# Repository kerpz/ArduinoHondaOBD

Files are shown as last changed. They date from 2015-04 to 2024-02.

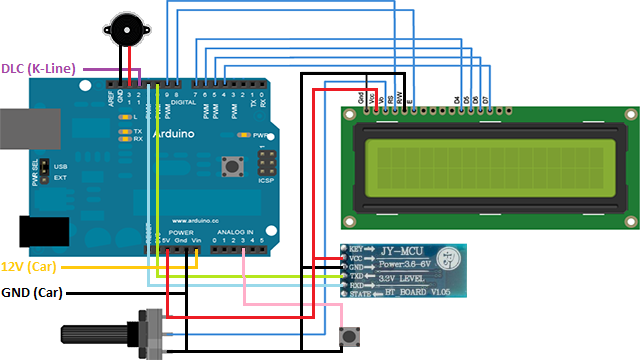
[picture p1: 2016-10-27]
images/UNI_wiring.png

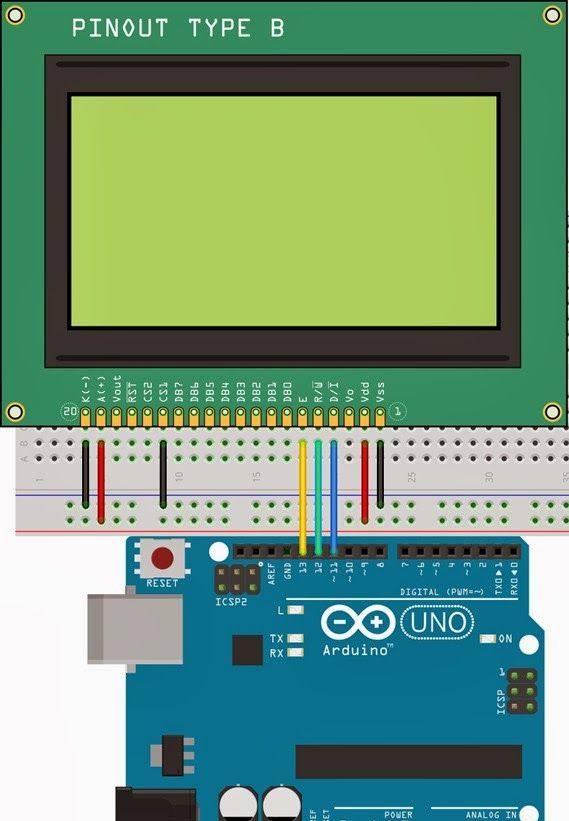
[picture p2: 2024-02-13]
hobd_u8g/wiring.jpg

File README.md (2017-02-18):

ArduinoHondaOBD
===========

An arduino code that reads Honda OBD Protocol and translates it to ELM327 protocol.
I use Torque app to read and display the data on my android phone (via bluetooth),
and a LCD (2x6) to display it on my car's dashboard.

Please refer to the screenshots below.

Applications
--------
* Datalogging
* Diagnostics
* Trip Computer
* Etc

Supports
--------
* Honda ECU's before 2002

Files
-----
* hobd_uni - unified code for ELM bluetooth and LCD display with other improvements.
* hobd_elm - implements Honda OBD to ELM OBD2 protocol (bluetooth) - not updated
* hobd_lcd - implements Honda OBD to LCD display - not updated
* UNI_wiring.png - Unified wiring diagram for arduino UNO (compatible)

Wiring for hobd_uni (Joined ELM and LCD codes)
--------------------
    Honda 3 Pin DLC           Arduino Uno
    Gnd --------------------- Gnd
    +12 --------------------- Vin
    K-line ------------------ Pin12

    HC-05 Bluetooth           Arduino Uno               
    Rx ---------------------- Pin11
    Tx ---------------------- Pin10

    LCD 16x2                  Arduino Uno               
    RS ---------------------- Pin9
    Enable ------------------ Pin8
    D4 ---------------------- Pin7
    D5 ---------------------- Pin6
    D6 ---------------------- Pin5
    D7 ---------------------- Pin4
    VO ---------------------- 10k Potentiometer (+5V to Gnd)

    Piezo Buzzer              Arduino Uno               
    (+) --------------------- Pin13
    (-) --------------------- Gnd

    Tact Switch               Arduino Uno               
    (+) --------------------- Pin17 (A3)
    (-) --------------------- Gnd

    Voltage Divider           Arduino Uno               
    +12V divider circuit ---- Pin14 (A0)
    (680k ohms and 220k ohms)

UNI Wiring Image

Wiring for hobd_elm (Deprecated use hobd_uni)
--------------------
    Honda 3 Pin DLC           Arduino Uno
    Gnd --------------------- Gnd
    +12 --------------------- Vin
    K-line ------------------ Pin12

    HC-05 Bluetooth           Arduino Uno               
    Rx ---------------------- Pin11
    Tx ---------------------- Pin10

Wiring for hobd_lcd (Deprecated use hobd_uni)
---------------
    Honda 3 Pin DLC           Arduino Uno
    Gnd --------------------- Gnd
    +12 --------------------- Vin
    K-line ------------------ Pin12

    LCD 16x2                  Arduino Uno               
    RS ---------------------- Pin9
    Enable ------------------ Pin8
    D4 ---------------------- Pin7
    D5 ---------------------- Pin6
    D6 ---------------------- Pin5
    D7 ---------------------- Pin4
    VO ---------------------- 10k Potentiometer (+5V to Gnd)

Screenshots (LCD 16x2)
---------------

LCD Screenshot 01
LCD Screenshot 02
LCD Screenshot 03

Screenshots (Andorid App TORQUE)
---------------

TORQUE Screenshot 01
TORQUE Screenshot 02
TORQUE Screenshot 04
TORQUE Screenshot 03

NOTES
-----
* Added button for changing page (5ms) and changing ecu mode (3s).
* Added Fault codes reader @ lcd page 3
* Added LCD @ I2C support
  - #define LCD_i2c TRUE // Using LCD 16x2 I2C mode
* Added direct HOBD access API (ELM mode) used for undefined PIDs on OBD2
  - // direct honda PID access
  - // 1 byte access (21AA) // 21 = 1 byte, AA = address
  - // 2 bytes access (22AA) // 22 = 2 bytes, AA = address
  - // 4 byte access (24AA) // 24 = 4 bytes, AA = address
* Added direct Arduino Pin access API (ELM mode) used for keyless entry and other stuff
  - // set arduino pin (ATSAPNNX) // NN = pin, X = value (value is 1 or 0)
  - // get arduino pin (ATDAPNN) // NN = pin
* Tested on P2T ODB2 stock and P30 ODB1 chipped

TODO
-----
* Add 128x64 LCD @ SPI support
* Add 20x4 LCD @ I2C support

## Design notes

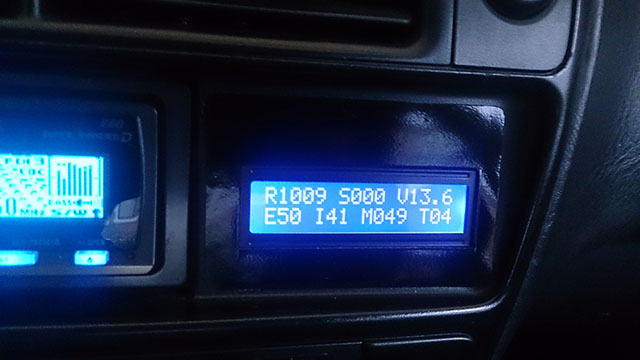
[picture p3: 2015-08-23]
images/LCD_02.png

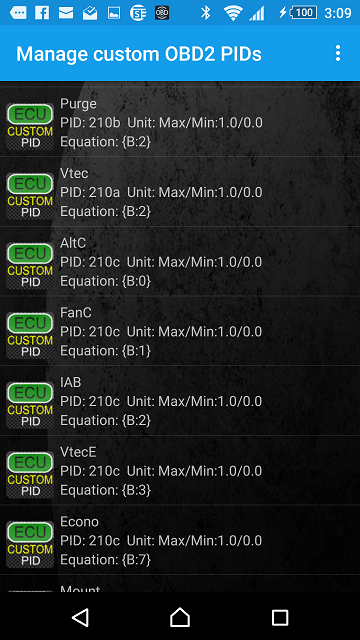
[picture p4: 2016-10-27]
images/TORQUE_05.png

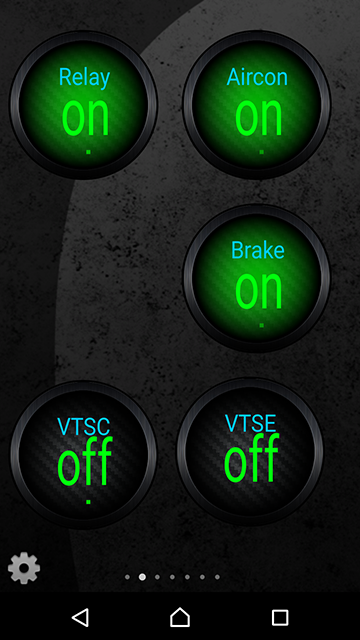
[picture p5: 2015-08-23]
images/TORQUE_03.png

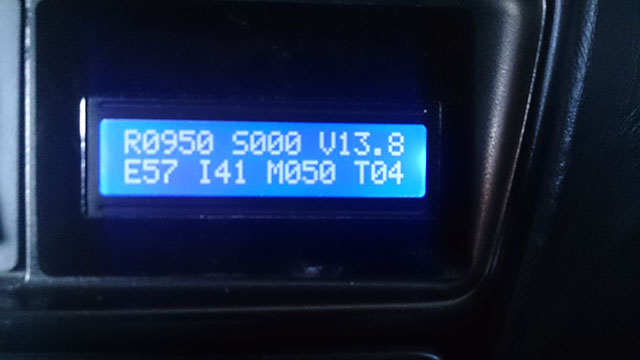
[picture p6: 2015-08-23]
images/LCD_03.png

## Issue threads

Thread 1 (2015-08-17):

Run on Nano with 328P ?

mr-sneezy, 2015-08-17:
I'm keen to try this code out on my Honda from 1999.
It looks like the code would run on Arduino Nano with 328P which I already have on hand.
Would there be some reason that it would not be suitable ?
Regards,
Martin

kerpz, 2015-08-17:
Hi martin,

It should run fine on a 328p chip, in fact Im running on a DIY board with 328 chip and UNO bootloader.

Regards, 

Philip B.

Sent from Yahoo Mail on Android

From:"Martin" <notifications@github.com>
Date:Mon, Aug 17, 2015 at 5:19 PM
Subject:[ArduinoHondaOBD] Run on Nano with 328P ? (#1)

I'm keen to try this code out on my Honda from 1999.
It looks like the code would run on Arduino Nano with 328P which I already have on hand.
Would there be some reason that it would not be suitable ?
Regards,
Martin

—
Reply to this email directly or view it on GitHub.￼

mr-sneezy, 2015-08-18:
Great, I did think there would be no problem, but it's good to get
confirmation.

I'll put this all together later this week and see how it goes on the
weekend hopefully.
If you want I'll take some photos and make an Eagle schematic for your
documentation on Github.

I'd like to add some code for checking error codes, and I'm wondering if
there is enough CPU time available to run a OLED display in lieu of the
16x2 Hitachi.

Regards,
Martin

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

---
This email has been checked for viruses by Avast antivirus software.
https://www.avast.com/antivirus

kerpz, 2015-08-19:
Hi martin,

That would be a great contribution.

Thanks and more power :)

Sent from Yahoo Mail on Android

From:"Martin" <notifications@github.com>
Date:Tue, Aug 18, 2015 at 7:35 PM
Subject:Re: [ArduinoHondaOBD] Run on Nano with 328P ? (#1)

Great, I did think there would be no problem, but it's good to get
confirmation.

I'll put this all together later this week and see how it goes on the
weekend hopefully.
If you want I'll take some photos and make an Eagle schematic for your
documentation on Github.

I'd like to add some code for checking error codes, and I'm wondering if
there is enough CPU time available to run a OLED display in lieu of the
16x2 Hitachi.

Regards,
Martin

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

---
This email has been checked for viruses by Avast antivirus software.
https://www.avast.com/antivirus

—
Reply to this email directly or view it on GitHub.￼

mr-sneezy, 2015-08-22:
Update:
The sketch is running on the Nano fine, 16x2 LCD is working fine.
Added HC-05 module and set to 9600baud.
I now have the HC-05 bluetooth talking to Torque app.
I have 'Bluetooth Mode' indication on the LCD.
I see data on the K line pin on the breadboard.
I am yet to connect to the car because my Ebay cable has not arrived, I'll need to make something temporary to do it.

Philip, do you have a blog or other site where a discussion can be done  ?

kerpz, 2015-08-22:
Hi Martin,
The discussion was done at pgmfi.org before, but I think the site is down.BTW, I'll post some pictures I grabbed from my phone and my car.
Regards,Philip

     On Saturday, August 22, 2015 4:20 PM, Martin <notifications@github.com> wrote:

 Update:
The sketch is running on the Nano fine, 16x2 LCD is working fine.
Added HC-05 module and set to 9600baud.
I now have the HC-05 bluetooth talking to Torque app.
I have 'Bluetooth Mode' indication on the LCD.
I see data on the K line pin on the breadboard.
I am yet to connect to the car because my Ebay cable has not arrived, I'll need to make something temporary to do it. Philip, do you have a blog or other site where a discussion can be done ?—
Reply to this email directly or view it on GitHub.

mr-sneezy, 2015-08-26:
I see the photos Philip, looks great. Looking forward to getting mine finished soon too.
BTW in researching the Honda OBD protocol I found a list of dlc command requests somebody has compiled, around 200 of them. Do you have something like that already to work from already ?
I could post it here.

kerpz, 2015-08-26:
Yes, anything that could improve this project would be a great help. I think there's a lot to be done in here. code faults scanning is not yet implemented.

mr-sneezy, 2015-08-27:
I hope this is actually useful, I'm collating and cleaning it all up after a google translation (for my own use anyway). This is not the list I mentioned above, as I don't think that one is very relevant after another look at it today. Will look over it again later.

The info below is headed by a URL to the source before each section, so credit goes to the original poster for documenting the info, not me.
There is a fragmented description of 32 bytes of DTC (from 0x40h to 0x50h it says in the second section) that may help out, also mention of ECU ID on 0x76h in that second block of info.
--------------------------------------------------------------------
[about Fault Codes ?]
http://hondamotor.ru/board/index.php?showtopic=98035&st=80&p=1626275&#entry1626275

Total: in the log can fall 32 bytes to describe the error.
These 32 bytes are the description of the 64 bugs.
 such a response is as follows: 00 02 00 20 ... (Hex View)
numbering errors in Honda starts with 0 (0-error ECU, 1 - error of the first sensor O2, 2 - the second O2 sensor error ...)
 in this example
00 ------> (lower 4 bits 0, upper 4 bits 0) ---> 0 - error0 (no)  0 - error1 (no)
02 ------> (lower 4 bits 2, upper 4 bits 0) ---> 2 - error2 (yes) 0  -error3 (no)
00 ------> (lower 4 Bits 0, upper 4 bits 0) ---> 0 - error4 (no)  0 - error5 (no)
20 ------> (lower 4 bits 0, upper 4 bits 2) ---> 0 - error6 (no)  2 - error7 (yes)
...........................
So Makar parse all 32 bytes. (The error codes are the same as blink codes) checked in several logs. And local expo error falls under the reduced treatment.
 
[about Command values (including DTC?) ?]
http://hondamotor.ru/board/index.php?showtopic=98035&st=120
The amount is considered to be just 256 minus the sum of all the bytes of the request or response, if it turns out is less than 0, then add 256
Enum ValuesOffset: byte
RPM = 0x00, // Turnover (2 bytes)
VSS = 0x02, // speed
Flag1 = 0x08, // 15 0-SW Starter 1-SW AC 3-SW Brake
Flag2 = 0x09, // 16 3- SCS self-diagnosis
Flag3 = 0x0A, // 17 2-VTS Vtec Control
Flag4 = 0x0B, // 18 0-MainRelay 2-O2Heater 5 -Engine
Flag5 = 0x0C, // 19 3-VTEC E 7-Econo
Flag6 = 0x0D, // 20
Flag7 = 0x0E, // 21
Flag8 = 0x0F, // 22
ECT = 0x10, // pace antifreeze
IAT = 0x11, / / temperature
 MAP = 0x12, // the pressure in the inlet
PA = 0x13, // atmospheric pressure T
PS = 0x14, // dross valve sensor
O2 = 0x15, // lambda sensor or lean
Bat = 0x17, // voltage onboard network
ALTF = 0x18, // Alternator FR Signal (ALTF) signal control board voltage
CorrCT = 0x20, // krastkovremennaya fuels correction
CorrLT = 0x22, // fuels long-term correction
Inj = 0x24, // ignition (2 bytes)
InjAdv1 = 0x26, // something with the ignition
InjAdv2 = 0x27, // something with the ignition
IAC = 0x29, // The Idle air control valve, or IACV regulates the car's idle based on the coolant temperature.
Knock = 0x3C, // Knock Sensor

Errors1 = 0x40, // Pars half a byte, half-byte if not equal to 0, it means
Errors2 = 0x50, // there is such an error code. Error number - offset nibbles displacement starts from 0
VSS2 = 0x61, // speed
RPM2 = 0x62, // Turnover (2 bytes)
ECT2 = 0x64, // pace antifreeze
IAT2 = 0x65, // temperature
MAP2 = 0x66, // the pressure in the inlet
PA2 = 0x67 // Atmospheric pressure
TPS2 = 0x68, // dross sensor zaslonui
Bat2 = 0x69, // voltage onboard network
O22 = 0x6C, // lambda sensor or lean
CorrCT2 = 0x6D, // krastkovremennaya fuels correction
IAC2 = 0x6E, // The air control valve Idle, or IACV regulates the car's idle based on the coolant temperature.
ECUID = 0x76 // ECU ID

Flags]public enum HOBDFlags: ulong
AllOff = (ulong) 0
Starter = 1 << 0
AirCondition = 1 << 1
PASPressure = 1 << 2
VTECPressure = 1 << 7
Brake = 1 << 3
SCS = 1 << (3 + 8), self-diagnostics //
VTSControl = 1 << (+16 2)
MainRelay 1 << = (0 + 24)
O2Heater << 1 = (2 + 24)
CEL = 1 << (5 + 24)
Engine 1 << = (5 + 24)
VTEC_E = 1 << (3 + 32)
Econo = 1 << (7 + 32)
ACClutch = 1 << (1 + 24)
O2Heater2 << 1 = (6 + 24)
FAN = 1 << (1 + 32)
------------------------------------------------------------------------
If it's all useless rubbish then I apologize in advance :)

mr-sneezy, 2015-08-27:
I have no idea why I have bold text in the last line, it's not shown while editing....

kerpz, 2015-08-28:
Yup found that already, but will double check maybe i missed something.  ￼ 

Sent from Yahoo Mail on Android

From:"Martin" <notifications@github.com>
Date:Thu, Aug 27, 2015 at 5:20 PM
Subject:Re: [ArduinoHondaOBD] Run on Nano with 328P ? (#1)

I have no idea why I have bold text in the last line, it's not shown while editing....

—
Reply to this email directly or view it on GitHub.￼

mr-sneezy, 2015-08-28:
These bits were of most interest perhaps.

Errors1 = 0x40, // Pars half a byte, half-byte if not equal to 0, it means
Errors2 = 0x50, // there is such an error code. Error number - offset nibbles displacement starts from 0

Total: in the log can fall 32 bytes to describe the error.
These 32 bytes are the description of the 64 bugs.
such a response is as follows: 00 02 00 20 ... (Hex View)
numbering errors in Honda starts with 0 (0-error ECU, 1 - error of the first sensor O2, 2 - the second O2 sensor error ...)
in this example
00 ------> (lower 4 bits 0, upper 4 bits 0) ---> 0 - error0 (no) 0 - error1 (no)
02 ------> (lower 4 bits 2, upper 4 bits 0) ---> 2 - error2 (yes) 0 -error3 (no)
00 ------> (lower 4 Bits 0, upper 4 bits 0) ---> 0 - error4 (no) 0 - error5 (no)
20 ------> (lower 4 bits 0, upper 4 bits 2) ---> 0 - error6 (no) 2 - error7 (yes)
...........................
So Makar parse all 32 bytes. (The error codes are the same as blink codes) checked in several logs. And local expo error falls under the reduced treatment.

mr-sneezy, 2015-08-28:
I note that the author suggests that the error code match the blink code numbering. Would seem logical.

kerpz, 2016-06-24:
Working, on adding this stuff

mr-sneezy, 2016-06-24:
Cool.
As it happens I've restarted the customisation of your code to add some external sensors (3x DS18B20's), to report through to the Torque app. I've dropped the LCD code as it's going to be hard to get enough data on it for my liking and I don't really want to mount a permanent LCD in a classic car like the S2000.
What may help us both is that I have a bench test ECU running now, with original MAP and ECT plus pots for TPS, IAT, O2. With this I could force on fault codes to test with you.
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

kerpz, 2016-06-25:
Wow, that's great :)

Closed 2021-05-30.

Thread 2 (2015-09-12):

Success and feedback.

mr-sneezy, 2015-09-12:
Hi Philip.
I took the Ebay Honda OBDII cable and cut off the 16-pin plug end (mine came wired for CAN on pin-14 not K-line on pin-7 anyway). I connected up the ArduinoNano/LCD/Bluetooth on the protoboard to it, and we had nearly instant success on my 1999 Honda S2000 (Australian delivered version). I get data from the HondaOBD converter on my Android phone through the Torque app, I just had to set the adapter speed to slow in the Torque settings first.

Feedback.
I have not yet fully setup Torque with the relay indications like you have, but the basics were working with the default gauge set.
The data mostly looks right, but coolant temp indicates around 100C at a real measured 80C (I used a thermocouple gauge on the radiator hose near the engine and then confirmed again with an IR thermo gun).
Also the coolant temp reads 155C on Torque when the car is off but the Arduino and BT are on. Would be better perhaps to read 0C when there is no valid ECU data perhaps, if this can be done.
The data refresh rate is quite slow on torque, I have not looked at how you set the request timing but it would be nice to update data faster if it's at all possible.
Would you know what the theoretical max baud or request rate of the ECU is ?

I'll have another look at your Torque screen photos and setup my Android device the same and have another look at it tomorrow.
Now that it's running on the protoboard I'm intending to create an Eagle PCB for it. I'll mount the Nano module, the Bluetooth module and regulator on it. LCD too probably but I don't like the white-on-blue one I have right now and will source another. Also going to see what I can do about some indicator leds on the K-line side as some comms feedback to the user (it's nice to know it's running on the ECU side).
Thanks,
Martin

kerpz, 2015-09-13:
Awesome

About the coolant values the readings comes from th ECT sensor, which is attached on the engine block. and when the car is off I think the reading will be the last data since it will return a NO_DATA value.

mr-sneezy, 2015-09-14:
Philip have you considered putting a warning LED driven from the Arduino, that triggers at preset ECT (say 100C) ?
I am looking for a RGB backlit 16x2 LCD as an option to change colour when values go out of normal range. Adafruit has them, and few other vendors...

kerpz, 2015-09-15:
Yes, I have them in the latest commit, I used it to avoid overheating, the current value is 98 degrees. I used a piezo buzzer at pin 13

Sent from Yahoo Mail on Android

From:"Martin" <notifications@github.com>
Date:Mon, Sep 14, 2015 at 6:07 PM
Subject:Re: [ArduinoHondaOBD] Success and feedback. (#2)

Philip have you considered putting a warning LED driven from the Arduino, that triggers at preset ECT (say 100C) ?
I am looking for a RGB backlit 16x2 LCD as an option to change colour when values go out of normal range. Adafruit has them, and few other vendors...

—
Reply to this email directly or view it on GitHub.￼

Closed 2021-05-30.

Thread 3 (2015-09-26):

Question about ECT formula ?

mr-sneezy, 2015-09-26:
Hi Philip, where did you get the formula for the ECT calculation in degrees C ?
Regards,
Martin

kerpz, 2015-10-02:
I think from the hondamotors.ru furom they have the formula

mr-sneezy, 2015-10-04:
I found a look up table apparently read from an OBD1 ECU if I understand it right. here on an old Honda forum.
http://www.getglitched.com/pgmfiwiki/www.pgmfi.org/twiki/bin/view/Library/EngineCoolantTemperature.html
If it's valid then it perhaps could be used as a table in in the HondaOBD code, or used to validate the formula currently used.

I also found this website which can derive the formula for you from points on the curve.
http://rusefi.com/articles/measuring_temperature/Steinhart-Hart.shtml

Here's the sensor curve that Honda quote for sensor testing.
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

mr-sneezy, 2015-10-04:
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

kerpz, 2015-10-14:
nice

kerpz, 2015-10-14:
why is the E16 is less than I17 intake is hotter than the engine :D

Closed 2021-05-30.

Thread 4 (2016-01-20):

connect with chrome ecu software

dibugreen, 2016-01-20:
hi ..
i'm blind about arduino :).. wuff ..  see lot of awesome project based n arduino .. including this one :)..
is possible to connect your project with  FT232RL FTDI USB to TTL ..(maybe chrome application will accept this communication..)
sorry for my english..
and thx for advance

kerpz, 2016-01-26:
Yes, you can use arduino to connect your ecu to crome application, eliminating the use of usb ftdi to ttl connector.

dibugreen, 2016-01-29:
thx  very much .. i'll try lean arduino .of course based on your project help me very much  ..thx u very much sir ..

mr-sneezy, 2016-01-30:
Crome PC app connection.
Do you both mean to a PC via the bluetooth link ?
If so what Hardware and Port setting are used in Crome to connect to a stock ECU ?
Regards,
Martin

kerpz, 2016-03-07:
yes I think its possible with bluetooth too.

Closed 2021-05-30.

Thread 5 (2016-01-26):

List of DLC values and meanings ?

mr-sneezy, 2016-01-26:
Hi Philip,
I've recently forked your Arduino code and am attempting to add some features to it like additional temperature sensors..
I've been digging for Honda DLC command and response info from all over the place, but it occurs to me that you may have collated a sanitised list or spreadsheet of known values and new ones you may have found.
Would you have a document to share ?
It will allow me to reduce the overhead of trying to filter out bad info and do more coding.

Regards,
Martin

Closed 2021-05-30.

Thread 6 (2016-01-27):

Creation of the PID's supported bytes ??

mr-sneezy, 2016-01-27:
Hi Philip,
I've been trying to reverse the OBDII PID supported bytes you send to Torque, but I'm having trouble making sense of them.
else if (!strcmp(btdata1, "0100")) {
    sprintf_P(btdata2, PSTR("41 00 BE 3E B0 11\r\n>"));

I think BE 3E B0 11 are the bytes sent indicating to Torque which of the next 20h PID numbers are used (valid). I can't make sense of the bits though when converted to 32 bits (flags) compared to what's available from the Honda OBD (converted to OBDII numbering).
Is BE the high byte and 11 the Low ?
Did you create some sort of table to describe these bytes from HOBD to OBDII ?

kerpz, 2016-01-27:
Hi Martin,

I used this as my reference https://en.wikipedia.org/wiki/OBD-II_PIDs and the 0100 is a hardcoded reply which is based from https://en.wikipedia.org/wiki/OBD-II_PIDs#Mode_1_PID_00.

mr-sneezy, 2016-01-28:
Hi Philip,  thanks I used that reference too, I converted the four Hex values to 32 bits of binary as they describe but I can't see it align with the OBDII PIDs used by the code. If you have it can you post the binary strings you used to create the Hex bytes, it will help me know what I'm doing wrong from the Wiki info  (I hope).

mr-sneezy, 2016-01-28:
Also just see that the last bit of the four bytes is a flag to validate the next sequence 32 bits....
:{

mr-sneezy, 2016-01-28:
Also, I think the code you wrote below is not needed as the next flag PID after 20h is at 40h, not 30h

else if (!strcmp(btdata1, "0130")) {
    sprintf_P(btdata2, PSTR("41 30 20 00 00 01\r\n>"));

Excuse me if wrong :)

kerpz, 2016-02-03:
Yes, its a dead code afaik :)

Closed 2021-05-30.

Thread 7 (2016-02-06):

Using bit values in Torque app, not working for me ?

mr-sneezy, 2016-02-06:
Hi Philip,
Hey you may be able to help me understand why I can get the Torque app to show active relays and switches like you do, even though the ECU and Arduino are TX'ing the byte correctly to Torque.
 In the 'Test' function of the app's Edit Custom OBD2 PID editor (same as you images but in the edit option) I can see the brake and A/C flag bit changing in the third byte of the returned string shown, but I can't see the Equation output change from 0.0 when using the bit formula you use.

In your photos you show the method to get the bits from byte B, but should that not be byte C going by what the Torque app wiki says ?

Index number of byte in response denoted by Latin alphabet:
A-1 byte, B-2 byte,.., Z-26 byte,AA-27 byte,AB-28 byte,...BA,BB,...

Torque Pro Operations (For reference only)
abs(): Absolute value.
{X:B}: Verify if the bit B is set within the X byte.
[pid]: Refers to the pid number of a sensor.
val{Long Name}: Refers to another equation using its long name.

I actually tried A, B and C bytes in turn and still get no change  in the formula output or the virtual indicators...

mr-sneezy, 2016-02-06:
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

A screen shot with A/C active in byte string  but not showing in formula..

kerpz, 2016-02-08:
i think its reverse try {B:6}

mr-sneezy, 2016-02-09:
No, it turns out that Torque Pro (current version) takes the first three bytes of the Extended PID response to be header bytes, the fourth byte is A, the fifth is B, six is C etc. This is not documented any place I could see (the three bytes bit).
So the fix was too pad your 20XX commands with an extra byte, then torque works.
The equation that works then for Brake for example is {A:3}
For one of my extra temp sensors as an Extended PID it's just A

dibugreen, 2016-02-09:
what  protocol is using when connect to torque.thx

mr-sneezy, 2016-06-18:
Seems to be changed now that I updated the Torque app to the current app version. Back to your byte/bit conversion values and it works on my test ECU (now using a 1995 Accord ECU on my bench).

kerpz, 2016-06-20:
Awesome

Closed 2021-05-30.

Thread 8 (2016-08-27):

help with obd

tycs03, 2016-08-27:
hi sir, i was wondering if this code will also work for a arduino nano clone. i tried to compile the file and upload it to the nano and wired an hc-06 bluetooth adapter. the code i used was the hobd_elm. i followed the schematic you provided and wired up the bluetooth module to the arduino nano. i wired the rx d11 and tx to d10, k line to d12. im not really sure if that is correct but it seem logical to me. i have downloaded the torque app but seemed to be a totally diffrent app(updated), based on your photo.
torque app won't connect to at all gets nothing

kerpz, 2016-08-31:
Maybe you can try the hobd_uni, and you need to pair your hc-06 to your phone. BTW, what's the error?

tycs03, 2016-08-31:
i have tried hobd_uni, also i have paired my hc06 to my phone. torque app says no data did you select the right device. seems to be like arduino is not sending anything. By the way i am using a jdm p30 ecu (obd1) i was wondering if i could just wire the arduino directly inside the ecu ? using cn2 port ? i have checked dlc pins and everyting seems to be connected properly. i am thinking maybe i compiled the sketch incorrectly ? i have not much experience with arduino i just bought one cause i saw this hub of yours.

kerpz, 2016-08-31:
I've tested on p2t odb2 and p30 obd1, try to test with elm terminal app.

mr-sneezy, 2016-08-31:
I've tested on Nano with a P0A and a PCX OBDI ECU with no issues either...
If you are building on a protoboard then add indicator LED's with 1k resistors to the TX and RX to bluetooth module, and also to the ECU DLC pin from the Nano. This will tell you what the Arduino is doing easier.
Also the HC06 module needs to be set to use 9600 baud IIRC, and the activity LED should change from fast flash to slower double flash if the Android phone is connecting.

tycs03, 2016-09-01:
i have set the baud rate for the hc06 at 38400 could this be the issue, i set it this way, because chrome rtp requires this baud rate. il try to set it at 9600 see if it works. no its not on a proboard. i just soldered the wires directly to the arduino nano points as i don't have a proto board.

tycs03, 2016-09-01:
Well its working now. Only problem now is that rpm seems to be off. When i rev the engine the meter goes down to 0rpm?

tycs03, 2016-09-01:
And also the rpm is off. Im not sure about the other sensors like ect temp. And map

kerpz, 2016-09-01:
If you are using hobd_uni, the default proto is obd2, set it to obd1 since you are using p30 ecu. Btw are you using hc06 to tune your ecu? Chrome rtp?

tycs03, 2016-09-01:
How to set it to obd1? I haven't  really started to tune my car. I haven't even had the time to install the afr wideband.

tycs03, 2016-09-01:
Also tps has no signal?  (throttle)

tycs03, 2016-09-01:
I was planning to use the hc06 to data log. Althoug seems like the data stream seems to show some lag. Maybe il just use the ttl serial cable instead

tycs03, 2016-09-01:
I forgot currently i am using a stock jdm p30.  But i also have a chipped p28 ecu that i will be using to tune the engine.

tycs03, 2016-09-01:
Ok everything is working now. I was womdering if there  was some way to get tps to work?

kerpz, 2016-09-02:
All sensors are working fine with me.

tycs03, 2016-09-02:
Im not getting anu reading on throttle? And it shows a question mark. When i try to add a display

tycs03, 2016-09-02:
My bad everything is working. Thank you

tycs03, 2016-09-03:
Sir Philip is it possible to add pid for power steering switch?  I have tried the other pid and it works.  I have been meaning to test the brake switch that goes to the ecu and with i this confirmed it to be working. :-) also i have learned the characteristics of the eld. With the ALT PID this is a very nice diagnostic tool as well. Would be really great if it can also pull trouble codes from the ecu.

kerpz, 2016-09-07:
Yes, you can add it through Manage PIDS in torque's setting

tycs03, 2016-09-07:
Sir i dont really know anything about hex.  How do you get the hex values?

kerpz, 2016-10-27:
Hi haven't decode the power steering switch :(

fifthaxe, 2018-06-08:
@tycs03 did you successfully managed to plug the arduino on the CN2 port of your ECU ? Is the CN2 port and the DLC port the same ?

tycs03, 2018-06-13:
Hi. I wasnt able to do the obd gauge. I sold my car. As dlfar as i know its
cb2 and dlc port is not the same.

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

tycs03, 2018-06-13:
I was able to make the dlc using stock ecu. I never tried to connect it to
cn2 port. My objective for this was to be able to see data from a stock
ecu. Since obd1 ecu runs modfied code you i can see data from a computer.
Uaing crome

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

tycs03, 2018-06-13:
Oh by the way i have an obd1 with crome and i used bluetooth hc06 to
connect to tuner view. So i use your code on obd2 ecus. Sorry for the
confusion. I though you were the other guy i asked helped from. I never got
to try his code.

Regards,

Tycs03

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
>>> @tycs03 <https://github.com/tycs03> did you successfully managed to
>>> plug the arduino on the CN2 port of your ECU ? Is the CN2 port and the DLC
>>> port the same ?
>>>
>>> —
>>> You are receiving this because you were mentioned.
>>> Reply to this email directly, view it on GitHub
>>> <https://github.com/kerpz/ArduinoHondaOBD/issues/8#issuecomment-395807199>,
>>> or mute the thread
>>> <https://github.com/notifications/unsubscribe-auth/AUSqfL3mHlQfAxwtaecLKsoEHN7KVyQkks5t6p-ngaJpZM4JureS>
>>> .
>>>
>>

akilamarquiel, 2018-06-13:
hi guys. ever wonder of using wifi instead of a bluetooth?

Closed 2021-05-30.

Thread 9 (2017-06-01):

torque app not working on hobd_uni

abdullah381, 2017-06-01:
hello
you did very nice job btw. i appreciate your efforts. i used your sketch for my obd1 honda hobd_elm connects to torque app i need to know that can i get the fuel injection rate in miliseconds?

2nd question is the main question. i used hobd_uni . device display everything on lcd but torque app is nt connecting can you please explain the issue however torque is working fine on hobd_elm.
also i am getting rpm in wrong format for example if rpm is 1300 lcd showing 300 in hobd_uni. very most digit is not working ..

Waiting for your Replay
Thanks for wonderful inovation

kerpz, 2017-06-03:
Hi,
For Question #1 injector duration in ms is given and displayed on LCD page 2
For Question #2 (what ecu are you using? obd1 or obd2) the dafault mode is obd2 so i think you need to set the mode to obd1
Regards

abdullah381, 2017-06-03:
Thanks alot i am using obd1. And please let me know rpm on lcd showing last
3 digit not first digit like if rpm is 1356 screen is showing 356

Thanks

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

Ouassimf, 2017-06-03:
Somehow same issue,
Torque not reading. Did a debut of the bt serial and Torque is sending a lot of empty msg and the arduino is answering with NO DATA
Nevertheless the first message ATZ or AT0 go through and arduino answers with  Honda OBD 1

Same issue with lcd, Inccorrect RPM (maybe other parameters as well)

And finally when in DLC serial mode, the code never switch to Bluetooth mode despite incming serial data.
I had to comment out the dlcSerial mode to get bluetooth .

THank a lot for your great program ;)

abdullah381, 2017-06-03:
kerpz
i have reviewed the code and there is obd1 selected. as Ouassimf decribe above, he is also facing issue with connecting to torque and same RPM issue. can you check the code for us Please? Thanks for creating obd1 diagnotic. take care

abdullah381, 2017-06-05:
Any update? I am waiting for code update to diagnose fuel mileage.pleaseeee

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

kerpz, 2017-06-06:
I'll try to pull this code and test

abdullah381, 2017-06-14:
no i am using stock ecu. however code is working fine on lcd . i can see parameters

kerpz, 2017-06-14:
how about the rpm on lcd? btw also check hc-05 settings i am using 9600bps baud rate, maybe you are in 38400bps.

eugjr, 2018-02-26:
Hello, I'm facing the same issue. Torque comunicatting with bluetooth, on hodb_elm.
On hodb_uni, the LCD works with rpm errors, and no bluetooth connection with torque.

So far can't identify the difference between the codes.

kerpz, 2018-03-07:
Yep need to check it, some modifications has cause this issue. I guess :(

ExGeniusF, 2018-07-26:
Hello. In the version "hobd_uni" the connection on the bluetooth does not work. Although if you immediately flash "hobd_elm" the option, then the bluetooth normally works without problems.
HC-05 reset to the default settings and re-configured. Did not help. Tell me, what can I try to make it work?

greekuser, 2018-10-08:
hi, first of all a big THANKS to kerpz for the amazing work on producing this.
i have a '98 civic mb and i was designing a pcb and program to wire a bunch of diy sensors to the engine. yeah, i didnt know that my car had an odb1/dlc port for the same thing. So when i realised that, i ordered an elm module, wired the K-line only to see that it didnt work(of course since DLC uses different codes than OBDII). I was totally  amazed to find this project. i had the needed parts, put everything together, used "hobd_elm.ino",bluetooth and TORQUE lite app, connected to the DLC port and BOOM, ECU connected. every data works fine except RPM. comparing the files you will see that in "hobd_elm.ino" the RPM dlcdata is sent to bluetooth without conversion from OBD1 to OBD2. but in "hobd_uni.ino" is converted using "rpm = (1875000 / (dlcdata[2] * 256 + dlcdata[3] + 1)) * 4;" which is the corrent thing to do.remember TORQUE's built in sensors understands OBD2 protocol. so i changed the rpm code  to
"int rpm = (1875000 / (dlcdata[2] * 256 + dlcdata[3] + 1)) * 4;
 sprintf_P(btdata2, PSTR("41 0C %02X %02X\r\n>"), highByte(rpm), lowByte(rpm));"
and now RPM shows fine. i hope this helps other too.
Again, kerpz thank you for your time and work. i dont know where you found the honda obd1 protocol codes. i think my car has revived seeing all the data instantly.

Closed 2021-05-30.

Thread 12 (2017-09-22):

VIN? Unique ID?

SERBice, 2017-09-22:
Is it posible to obtain an unique id or vin from any car to show in the screen about the vehicle??

kerpz, 2017-09-22:
Its specific for honda

SERBice, 2017-09-22:
I want show vin on the screen for my accord 5th generation; f22b1 with p0a ecu.

Is possible obtain vin or uid from ecu on this years?

SERBice, 2017-09-23:
Is it posible to use mode 9 pid 02? How?

Thanks.

mr-sneezy, 2017-09-23:
You need to know the exact byte location of Hondas ECU or VIN data and then translate that to an OBD-II equivalent code. If we don't know this then it can not be done...

SERBice, 2017-09-23:
This Code (Line 547):

`    //byte h_cmd4[6] = {0x20,0x05,0x76,0x0a,0x5b}; // ecu id`

Gets an unique id? How apply it?

Maybe this?:
`dlcCommand(0x20,0x05,0x76,0x0a,data)) `

kerpz, 2017-09-27:
I had tried that byte location but i cannot see any significant data or ecu id on that location :(

SERBice, 2017-10-01:
How do I expel the  dlcCommand function to search for the vin or ID in the ECU ?, I will look for it

Daggers9, 2017-10-01:
You either need to trial and error, or find the correct offset code.

A Russian dude Reneman has an offset table I'm trying to get a hold of. Dip on pgfmi threw one up ages ago, there is some more info. Kinda dead thread now.

Btw, nice stuff kerpz, I'm yet to get a junk ECU to test it tho. :)

mr-sneezy, 2017-10-01:
There is some offset info in the first issue thread.
https://github.com/kerpz/ArduinoHondaOBD/issues/1
If you find any info that is more accurate or better than this it would be good to share it back to us here.
I do also have a docx file I compiled from various sources on my own fork.
Thanks,
Martin

SERBice, 2017-11-04:
I would like you to tell me how to "scan" the ecu byte to byte, if possible, of course.

In this way try to find my VIN, since I already know it would be easy to recognize if it is present or not.

How should I use the dlcCommand function to do this? it's possible?

Daggers9, 2017-11-04:
Hey I've been following this for a bit. In my research, what you are looking for is a set of codes, I forget what other people have called them, that allow you to communicate with the ecu. Look through some hodba forums, and look for work done by a guy called Dip/Didier. The PGFMI forums have the best stuff.

However I don't think you'll find VIN information on an ecu, as an ecu is just a part of the car, not the chassie it's self. It would be like putting the vin on your shocks or wheels or dash. It just doesn't make sense. A VIN is only relevant to the chassie and nothing else.

Daggers9, 2017-11-04:
Lol, thanks myself. you are looking for offset codes.

Daggers9, 2017-11-04:
Sorry the TLDR of it is, the PGFMI forums, have already covered how to trial and error offset codes.

Daggers9, 2017-11-04:
Apologies for the sporadic replies, I currently away from standard internet service, Ive been searching the forums to find the page which explains the trail and error process, but its tough using only my phone. I know I have saved the relevant pages on my computer back home. I'll will be back home in a week, if you post back here around the 14th, I will send you the links I have bookmarked.

Daggers9, 2017-11-20:
http://forum.pgmfi.org/viewtopic.php?f=57&t=5871&start=75&sid=ef6d52919f8a792ea306ae398b685e4c

Closed 2021-05-30.

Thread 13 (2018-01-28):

Honda specific pids

overzealus, 2018-01-28:
Hello! I can see from screenshot that you have Honda specific pids.
Can you share them? In a csv file or something.
And can you tell, what Honda models (or ages) do they fit?

Daggers9, 2018-03-12:
Added some raw data to wiki

overzealus, 2018-03-12:
Could you be so kind to post csv from torque with equations and header info?

Daggers9, 2018-03-12:
I'm not quite sure what you are asking for.

but I'm not using torque or any similar apps. I'm simply working on an arduino based stand alone diagnostics device.

overzealus, 2018-03-12:
I’m talking about torque app screenshots, that you have in Readme.md

Closed 2021-05-30.

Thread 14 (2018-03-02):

Arduino Uno HC-06 Bluetooth Module

mikewing94, 2018-03-02:
Hello,

I am trying to get this working for my Honda S-MX 1997 (OBD1).

Will this work with the HC-06 Bluetooth module, as my phone doesn't seem to want to connect to it currently?

Thanks

eugjr, 2018-03-05:
Hello, first of all, make sure your HC-06 board is working properly. You can try some simple Arduino codes to make sure you can pair your BT module and cellphone.
Also make sure the wiring is correct.

mikewing94, 2018-03-10:
Thank you, I know the HC-06 board is working properly as I have used it in other projects previously. I will re-do the wiring tonight so I can be certain it is correct though.

mr-sneezy, 2018-03-10:
I use one of the many Android BT serial terminal apps to test my HC-05 modules.

kerpz, 2018-11-02:
Fixed, added a delay on the bt proc

Closed 2018-11-02.

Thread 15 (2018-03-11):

No Input messages

mikewing94, 2018-03-11:
Does the program currently give any error messages on the LCD if there is no data being read? I have followed the diagram for the wiring, but I am yet to test it on the car, I am just being shown a blank screen currently, is this normal?

Thanks

Daggers9, 2018-03-12:
What version of the code are you using?

HOBD_UNI
or
HOBD_LCD

mikewing94, 2018-03-12:
HOBD_UNI
    On Monday, March 12, 2018, 7:58:01 AM GMT, Daggers9 <notifications@github.com> wrote:

What version of the code are you using?

HOBD_UNI
or
HOBD_LCD

—
You are receiving this because you authored the thread.
Reply to this email directly, view it on GitHub, or mute the thread.

Closed 2021-05-30.

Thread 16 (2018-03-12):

Intent to create Wiki

Daggers9, 2018-03-12:
Essentially I'd like to create a Wiki for this project for some of the less known/lost pieces of information required to communicate and translate honda ecu data

Information that I'd like to source and confirm

PID/ECU communication | I've already found a few reliable sources from various forums that appear to be correct, next steps for this is to make a master spread sheet

--

ECU Byte/Word conversion | There are various readings made by the ECU which are stored as values between 0 and 255 or 511. After the micro controller receives one or two byte pieces of information, it must convert these values into real world values like temperatures, degrees of advance, percentages...

I'd like to collect and confirm as many conversion formulas and sources as possible.

--

If anybody has any sources (i.e. forums) or and raw data that could be formatted into a document by myself, I'd love to know about it.

mikewing94, 2018-03-12:
Sounds great!
Especially for less well known Hondas, (I am currently trying to get this working with a Honda S-MX 1997.)

I think it would also be good if we could get together peoples photographs of wiring etc... I am 99% sure I have a wiring problem with my project currently, but cannot see where from looking at the diagram on here...

Daggers9, 2018-03-12:
My understanding is that this information will be mostly universal for all Hondas that have ecus before 2002.

My project wiring is completely different from this project as I've created an embedded, stand alone device using completely different display components and a bluetooth delete

mikewing94, 2018-03-12:
I'd be happy to get anything working currently, I have had bluetooth issues in the past so a stand alone setup would be fine for me also. Would you mind sharing your setup if possible?

Closed 2021-05-30.

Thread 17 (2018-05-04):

ArduinoHondaOBD

sw2ncx, 2018-05-04:
Is that code working with Ectune????
Or only stock and Crome?

ExGeniusF, 2018-07-18:
Hey. Is there a table in the csv format for App TORQUE? In the screenshot there are added PIDs, I do not understand how to add them correctly.

rubensx, 2021-03-22:
> Hey. Is there a table in the csv format for App TORQUE? In the screenshot there are added PIDs, I do not understand how to add them correctly.

to put csv file in torque you need a file explorer on your android phone like a "X-plore'. app, and root rights to put CSV in the extendedPiDs folder under .torque folder!

Closed 2021-05-30.

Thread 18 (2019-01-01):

Honda 12v to Arduino VIN and Voltage Divider

bonaminGR, 2019-01-01:
Hello !!! I've been trying to put together a diagnostic and datalogging board for my 98 EK, but I stumbled upon a problem. I'm quite new to both programming and electronics so here are my questions !

The diagram shows the 12V + Ground pins from my Honda's 3Pin Connector going straight to the Arduino board. But I tried that with an Arduino Pro Mini, and apparently I fried it. :D

1. Is it possible that I wasn't supposed to connect it like that..?  Do I need to use something BEFORE the board to drop the voltage to smaller numbers...?

2. I used an Arduino Pro Mini and I connected the 12V of the car on the RAW pin. That is the pin where you're supposed to connect up to 12V as I found on the documentation. But when my car is running, isn't it's voltage like 14V or something? Was that the cause ? Or I should not use a pro mini board at all ?

3. Can I power the board externally using USB or something, and ONLY use the K-Line pin from the car..?
Or it NEEDS the car's power and ground wires to work ?

4. There is a mention of a VOLTAGE DIVIDER inside the readme. With two resistor Values. Where each resistor goes and why do I use a voltage divider in the analog0 input on the Arduino ?

I need some help here folks, I can't figure it out !!
I ordered some new Arduino Pro Mini boards because I don't want to risk the Uno that I'm using as a test bench on my PC. But I need to know if I'm doing something wrong, and how the exact connection should be !

THANKS A LOT IN ADVANCE !!!!
PS. Your project is REALLY interesting ! Especially for a Honda fan like me ! <3

mitchschaft, 2019-01-02:
You need a multimeter to test voltages. But it's supposed to be 12v on the middle pin of the DLC. Are you sure you are using the right connector? How do you know it's fried? Because the arduino pro mini has an onboard input vintage regulator that can handle 16v. And the Uno can handle up to 20v I think.

What country are you in? I'm not sure if you have both the 3pin DLC and the full 16pin obd2 port. You could use either one.

But it sounds like you connected it right because the mini accepts 12v to raw according to the pinout charts.

mr-sneezy, 2019-01-02:
Some clone Arduinos boards use a cheap regulator that is actually only capable of +12V maximum, and some will blow up around 14V. I've experienced it myself.
You could put two or three 1N4001 diodes in series on the +12V-RAW line to drop about a volt or so.
If possible I try to use a quality regulator from car power down to +5V and power the Arduino board from that.
One point, if you have a chipped P30 ECU, does the new chip still support HOBD protocol ?
This might be an unknown...

bonaminGR, 2019-01-02:
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

First of all, it's funny how I've been JUST reading this: https://github.com/mr-sneezy/ArduinoHondaOBD_Extra which apparently is your contribution to this Arduino-Honda world ! :D

I've just contacted my Tuner asking these questions. And apparently my ECU is tuned using Crome Gold.
Do you know if that actually supports the HOBD protocol ?

He told me that you can buy datalogging apps, software and hardware to use with ECTune or Hondata S300. But I don't want to do that. I want to experiment. That's the beauty of it.

mitchschaft, 2019-01-02:
What are you guys referring to when you say HODB protocol? Is that another way of saying ODB1? Sorry, I'm from the US and I haven't heard that nomenclature before.
That chipped p30 ecu is still obd1 all the way. Do you know if it's JDM? I guess not if it came from Germany. I believe crome gold is based off the p30 map to begin with.

Otherwise, Crome Gold uses the QD3 protocol to rtp for datalogging. You'll have to have a Crome dealer's license and a usb data cable to get into all that (or cracked Crome software). Or go with another brand like your tuner suggested. A few hundred bucks either way.

Do you know what version of Crome is on your p30? Do you mess with that at all or just take it to him when you need work done?

As far as your busted arduino minis, reflash the bootloaders using your UNO as an isp and that will get them back up and running.

mr-sneezy, 2019-01-02:
"What are you guys referring to when you say HODB protocol? Is that another way of saying ODB1? "

I'm not sure I've ever seen a document that shows a list of parameters for OBD1, only OBD-II so not sure if  they mean the same thing with Hondas ?
Send me a link to an OBD1 proctol document and I'll compare, or you can have a look at Kerps code and let us know.

I derived the bulk of what I know of the 'HOBD' byte structure and parameters from Kerps code and a bit of Russian software called HOPE (Honda OBD Protocol Examiner).

mitchschaft, 2019-01-02:
Oh no, I think I get it. I'm way out of my depth in that case! I would have a lot of studying to do to catch up on that level and I don't want to waste anyone's time. I have nothing to contribute unless you need anything from a US obd2 96 Accord LX manual f22b2 ecu.

 I also have an auto ecu lying around from a 97 Odyssey van f22b6 engine I tried to get working with my setup to take advantage of the fuel maps and cam timings after swapping the cam gear from reading on a forum. The ecu seal turned out to be conjecture because you get nothing but a lot of backfire on deceleration even after converting the ecu to manual, which you can do with obd2 just not 100%. It still sees auto components that I think is in the programming. It doesn't do proper fuel cutoff on deceleration. But enough blabbing. I'll get back to building this device.

bonaminGR, 2019-01-02:
My ECU is JDM. I did an engine swap and rebuild, so we used a JDM P30 ECU.
I found out online, that Crome actually SUPPORTS BOTH the Honda STOCK protocol for Datalogging and its own custom protocol but you must choose which when you're burning the ROM. I will have to check my ECU to see if this is actually the case with me.
I'm gonna try running the firmware on my Uno but with external power for safety to see what happens and I'll keep you informed if it works with Crome.

Just for the fun of it, I'm gonna try it on my friends completely stock D14 civic.

bizi27, 2019-04-18:
Hey i have the same problem no info displayed on lcd. It shows the startup but no info about rpm, vss.... All on 0 :/ i tried through js pins from ecu but start to click in ecu so idk what should be wrong

Closed 2021-05-30.

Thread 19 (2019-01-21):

EK3 ECU not responding

Tobianas, 2019-01-21:
Hello, i have tried to do this project on my EK3 civic (D15Z6 engine with P2Y ECU).
Unfortunately my ECU is not responding with any code... I have tried it on my friends EK3 as well with the same result.
I have added a     Serial.print(Data[i])    when the data is being collected from the data steam for debugging and the serial does not show anything.
Does the ECU use a different way of communication ? Or any ideas what could be wrong ?
Im using the hobd_lcd.
Thanks for your response.

Closed 2021-05-30.

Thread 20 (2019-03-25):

Something wrong, any suggestion?

Gnoce, 2019-03-25:
Hi, I'm trying to make this project. I followed the wiring diagram (except for the 12V power supply that I diverted to a stabilizer with 5V output connected to the Arduino 5V). The program has been loaded without errors but the LCD backlights is off and only the squares of the high line are highlighted, both when it's connected to the PC via USB and when it's connected to the 3-pin DLC of the car. The car is a '97 Prelude (P5M). When I connect the DLC, the green Arduino LED and the yellow Rx one light up. If I press the button the Rx turns off and it doesn't turn on again. I had to reset Arduino and reload the program. What can I do? Is there any correlation with the fact that I'm feeding at 5V? I'm using the Uni version.

mr-sneezy, 2019-03-26:
High line dark only means the LCD is not initialized by the MCU properly. Check you have the data and control lines in the right order first as this should work without the car connected (just power).

Gnoce, 2019-03-26:
I will try to connect via IC2, maybe it helps and surely reduces the wiring.

Ottieni Outlook per Android<https://aka.ms/ghei36>

________________________________
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

Gnoce, 2019-03-26:
Display is working!!! I've to change 0x3f with 0x27. Now I can try if the DLC work too!

Gnoce, 2019-03-30:
Ok now there is another issue. Everything seems work but after a while the display starts showing strange characters. The only way to get it working again is to turn off the power for at least 15 seconds. The problem occurs randomly after few seconds or minutes, both connected to the car or connected to the PC via USB. If you go past the third minute of this video you can see what happens. Do you have any suggestions? [https://youtu.be/m_F93ymSCmA](url)

mr-sneezy, 2019-03-31:
My experience with getting character corruption on hitachi style LCD's is it's mostly caused by writing to it too fast, or from noise or bad connections on the LCD control lines, or by wires that are too long (having coupling between them), especially bad in the 4-bit data modes.
BTW I have no clue about your post about 0x27, please explain ?

Gnoce, 2019-03-31:
Is the LCD inizialization line "LiquidCrystal_I2C lcd(0x3f, 2, 1, 0, 4, 5, 6, 7); I read that most LCD need another inzialization with 0x27 and not 0x3f. I'm not sure why everyone use this line "LiquidCrystal_I2C lcd(0x27, 2, 1, 0, 4, 5, 6, 7, 3, POSITIVE)" but the hobd_uni code trunk the line at 7. What does "3, POSITIVE" do?

kerpz, 2019-04-10:
Hi Gnoce,

That 2 parameter is for backlight, 3 is the backlight pin and POSITIVE is the polarity.
You can refer to LiquidCrystal_I2C.h

Regards

Gnoce, 2019-04-20:
Ok, I have redone the welds between IC2 and the LCD and now the display seems to work correctly. The problems are now the rev data on LCD and Torque. Torque cannot read also other data, the voltage display random numbers.  hobd_uni setted on OBD1 and HC-05 on 9600 baud . I have to try flashin hobd_elm and see. I forget to thank you for your great job kerpz!!!

Closed 2021-05-30.

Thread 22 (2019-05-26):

New version is something wrong ...@@...

snowcatjoey, 2019-05-26:
My Honda is 00" CRV in Taiwan, when I used "hobd_elm", It works very well!

When I try "hobd_uni" even "hobd_uni2", everything working..... but the RPM and Throttle and.... which value is become very low.

For example,  Throttle's value is from 11% become 0.8%, RPM's value is from 1500 become 300or200.

Is something changed in  "hobd_uni" ?

snowcatjoey, 2019-09-01:
I changed OBD1 mode to OBD2，all datas are working great! thx a lot!

Closed 2019-09-01.

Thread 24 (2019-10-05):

Wrong RPM

silenec, 2019-10-05:
Hi, first of all - great work!
I got it mostly working but in Torque, RPM is always (both with OBD1 and OBD2 selected) exactly 7224 rpm with the engine off and ~300 at idle. When I raise the rpm to ~3000, it shows even lower value (~170).
What can I try to make it work correctly? Honda_PCScanner.exe shows correct RPM.
Car is a d15z6 EK3 Civic with 37820-P2Y-G11 ECU (OBD2b I think).

silenec, 2019-10-06:
This is what I get with engine off: [https://i.imgur.com/GlQqP3l.png](url)
A=112
B=224
(256A+B)/4 -> (256*112+224)/4 = 7224

What should the A and B values normally be at 0 rpm?

silenec, 2019-10-06:
Alright I think I got it.

hobd_uni2 uses:
OBD1 (1875000 / (A * 256 + B + 1) ) * 4
OBD2 (A * 256 + B)

And this is what works for me in Torque v1.8.205:
**(1875000 / (A * 256 + B + 1) )**

I use it as a PID override for RPM and although the RPM is not 0 with engine stopped, it seems to be correct with engine running.

Closed 2019-10-08.

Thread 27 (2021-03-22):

RPM runs down instead rev up

rubensx, 2021-03-22:
Hi Kerps, nice work, I'm using a arduino uno and a HC-06 bluetooth as a simple bridge to torque, but, the RPM goes to another direction instead rev up when I hit the accel pedal!

I'm trying other codes but still no lucky

The ar is a P28 ECU honda EJ1 1995 d16z6

 else if (!strcmp(btdata1, "010C")) { // rpm
    if (dlcCommand(0x20, 0x05, 0x00, 0x02, dlcdata)) {   //Note 2 bytes used here
        if ((dlcdata[2] == 255) && (dlcdata[3] == 255)) {   //Trap a condition where my test ECU sends 255, 255 when engine is off
            dlcdata[2]=0;                                   //Set a 255 value to 0
            dlcdata[3]=0;
        }
        sprintf_P(btdata2, PSTR("41 0C %02X %02X\r\n>"), dlcdata[2], dlcdata[3]);
    }
    else {
      sprintf_P(btdata2, PSTR("DATA ERROR\r\n>"));
    }
  }

tested the original code, and this above, and still down the RPM

kerpz, 2021-03-26:
Hi Rubens, you need to change the mode to OBD1

kerpz, 2021-03-26:
`byte obd_select = 1;`  1 for obd1, and 2 for obd2 they have different encodings for rpm, p28 is obd2 I guess, so the value would be 2.

> Hi Rubens, you need to change the mode to OBD1

rubensx, 2021-03-26:
hi Philip, thank you for your help, but I guess I don't know how I put this "byte pbd_select = 1"

rubensx, 2021-03-26:
the P28 ECU is OBD1

kerpz, 2021-03-26:
> the P28 ECU is OBD1

which code did you use? the hobd_uni2?

rubensx, 2021-03-26:
I'm using this hobd_elm.ino and edit some parts, all other codes don't link ecu for me

rubensx, 2021-03-26:
`/*
 Author:
 - Philip Bordado (kerpz@yahoo.com)
 Hardware:
 - HC-05 Bluetooth module at pin 10 (Rx) pin 11 (Tx)
 - DLC(K-line) at pin 12
 Software:
 - Arduino 1.0.5
 - SoftwareSerialWithHalfDuplex
   https://github.com/nickstedman/SoftwareSerialWithHalfDuplex

 Formula:
 - IMAP = RPM * MAP / IAT / 2
 - MAF = (IMAP/60)*(VE/100)*(Eng Disp)*(MMA)/(R)
   Where: VE = 80% (Volumetric Efficiency), R = 8.314 J/°K/mole, MMA = 28.97 g/mole (Molecular mass of air)
   http://www.lightner.net/obd2guru/IMAP_AFcalc.html
   http://www.installuniversity.com/install_university/installu_articles/volumetric_efficiency/ve_computation_9.012000.htm
*/
#include <SoftwareSerialWithHalfDuplex.h>

SoftwareSerialWithHalfDuplex btSerial(10, 11); // RX, TX
SoftwareSerialWithHalfDuplex dlcSerial(12, 12, false, false);

const byte myTPSlow = 14;    //your cars zero throttle TPS byte value (trim to get 0% on OBD2 or leave at 0)
const byte myTPShigh = 231;  //your cars full throttle TPS byte value (trim to get 100% on OBD2 or leave at 255)
byte obd_select = 1;

bool elm_memory = false;
bool elm_echo = false;
bool elm_space = false;
bool elm_linefeed = false;
bool elm_header = false;
int  elm_protocol = 0; // auto

void bt_write(char *str) {
  while (*str != '\0')
    btSerial.write(*str++);
}

void dlcInit() {
  dlcSerial.write(0x68);
  dlcSerial.write(0x6a);
  dlcSerial.write(0xf5);
  dlcSerial.write(0xaf);
  dlcSerial.write(0xbf);
  dlcSerial.write(0xb3);
  dlcSerial.write(0xb2);
  dlcSerial.write(0xc1);
  dlcSerial.write(0xdb);
  dlcSerial.write(0xb3);
  dlcSerial.write(0xe9);
  delay(300);
}

int dlcCommand(byte cmd, byte num, byte loc, byte len, byte data[]) {
  byte crc = (0xFF - (cmd + num + loc + len - 0x01)); // checksum FF - (cmd + num + loc + len - 0x01)

  unsigned long timeOut = millis() + 250; // timeout @ 250 ms
  memset(data, 0, sizeof(data));

  dlcSerial.listen();

  dlcSerial.write(cmd);  // header/cmd read memory ??
  dlcSerial.write(num);  // num of bytes to send
  dlcSerial.write(loc);  // address
  dlcSerial.write(len);  // num of bytes to read
  dlcSerial.write(crc);  // checksum

  int i = 0;
  while (i < (len+3) && millis() < timeOut) {
    if (dlcSerial.available()) {
      data[i] = dlcSerial.read();
      i++;
    }
  }
  if (data[0] != 0x00 && data[1] != (len+3)) { // or use checksum?
    return 0; // error
  }
  if (i < (len+3)) { // timeout
    return 0; // error
  }
  return 1; // success
}

void procbtSerial(void) {
  char btdata1[20];  // bt data in buffer
  char btdata2[20];  // bt data out buffer
  byte dlcdata[20];  // dlc data buffer
  int i = 0;

  memset(btdata1, 0, sizeof(btdata1));
  while (i < 20)
  {
    if (btSerial.available()) {
      btdata1[i] = toupper(btSerial.read());
      if (btdata1[i] == '\r') { // terminate at \r
        btdata1[i] = '\0';
        break;
      }
      else if (btdata1[i] != ' ') { // ignore space
        ++i;
      }
    }
  }

  memset(btdata2, 0, sizeof(btdata2));

  if (!strcmp(btdata1, "ATD")) {
    sprintf_P(btdata2, PSTR("OK\r\n>"));
  }
  else if (!strcmp(btdata1, "ATI")) { // print id / general
    sprintf_P(btdata2, PSTR("HOBD v1.0\r\n>"));
  }
  else if (!strcmp(btdata1, "ATZ")) { // reset all / general
    sprintf_P(btdata2, PSTR("HOBD v1.0\r\n>"));
  }
  else if (strstr(btdata1, "ATE")) { // echo on/off / general
    elm_echo = (btdata1[3] == '1' ? true : false);
    sprintf_P(btdata2, PSTR("OK\r\n>"));
  }
  else if (strstr(btdata1, "ATL")) { // linfeed on/off / general
    elm_linefeed = (btdata1[3] == '1' ? true : false);
    sprintf_P(btdata2, PSTR("OK\r\n>"));
  }
  else if (strstr(btdata1, "ATM")) { // memory on/off / general
    elm_memory = (btdata1[3] == '1' ? true : false);
    sprintf_P(btdata2, PSTR("OK\r\n>"));
  }
  else if (strstr(btdata1, "ATS")) { // space on/off / obd
    elm_space = (btdata1[3] == '1' ? true : false);
    sprintf_P(btdata2, PSTR("OK\r\n>"));
  }
  else if (strstr(btdata1, "ATH")) { // headers on/off / obd
    elm_header = (btdata1[3] == '1' ? true : false);
    sprintf_P(btdata2, PSTR("OK\r\n>"));
  }
  else if (!strcmp(btdata1, "ATSP")) { // set protocol to ? and save it / obd
    //elm_protocol = atoi(data[4]);
    sprintf_P(btdata2, PSTR("OK\r\n>"));
  }
  //else if (!strcmp(data, "ATRV")) { // read voltage in float / volts
  //  btSerial.print("12.0V\r\n>");
  //}
  // sprintf_P(cmd_str, PSTR("%02X%02X\r"), mode, pid);
  // sscanf(data, "%02X%02X", mode, pid)
  // reset dtc/ecu honda
  // 21 04 01 DA / 01 03 FC
  else if (!strcmp(btdata1, "04")) { // clear dtc / stored values
    dlcCommand(0x21, 0x04, 0x01, 0x00, dlcdata); // reset ecu
    sprintf_P(btdata2, PSTR("OK\r\n>"));
  }
  else if (!strcmp(btdata1, "0100")) {
    sprintf_P(btdata2, PSTR("41 00 BE 3E B0 11\r\n>"));
  }
  else if (!strcmp(btdata1, "0101")) { // dtc / AA BB CC DD / A7 = MIL on/off, A6-A0 = DTC_CNT
    if (dlcCommand(0x20, 0x05, 0x0B, 0x01, dlcdata)) {
      byte a = ((dlcdata[2] >> 5) & 1) << 7; // get bit 5 on dlcdata[2], set it to a7
      sprintf_P(btdata2, PSTR("41 01 %02X 00 00 00\r\n>"), a);
    }
    else {
      sprintf_P(btdata2, PSTR("DATA ERROR\r\n>"));
    }
  }
  //else if (!strcmp(btdata1, "0102")) { // freeze dtc / 00 61 ???
  //  if (dlcCommand(0x20, 0x05, 0x98, 0x02, dlcdata)) {
  //    sprintf_P(btdata2, PSTR("41 02 %02X %02X\r\n>"), dlcdata[2], dlcdata[3]);
  //  }
  //  else {
  //    sprintf_P(btdata2, PSTR("DATA ERROR\r\n>"));
  //  }
  //}
//  else if (!strcmp(btdata1, "0103")) { // fuel system status / 01 00 ???
//    //if (dlcCommand(0x20, 0x05, 0x0F, 0x01, dlcdata)) { // flags
//    //  byte a = dlcdata[2] & 1; // get bit 0 on dlcdata[2]
//    //  a = (dlcdata[2] == 1 ? 2 : 1); // convert to comply obd2
//    //  sprintf_P(btdata2, PSTR("41 03 %02X 00\r\n>"), a);
//    // }
//    if (dlcCommand(0x20, 0x05, 0x9a, 0x02, dlcdata)) {
//      sprintf_P(btdata2, PSTR("41 03 %02X %02X\r\n>"), dlcdata[2], dlcdata[3]);
//    }
//    else {
//      sprintf_P(btdata2, PSTR("DATA ERROR\r\n>"));
//    }
//  }

//Fuel system status PID - Note - Verified bit 0 of 0F is Closed Loop flag via Custom PID so retest this code, seems probable that 0C bit 0 or bit 1 are PID 0103/4
  else if (!strcmp(btdata1, "0103")) { // fuel system status / 01 03
    if (dlcCommand(0x20, 0x05, 0x0F, 0x01, dlcdata)) { // flags 0F
      byte a = dlcdata[2] & 1; // get bit 0 on dlcdata[2]
      a = (dlcdata[2] == 1 ? 2 : 1); // convert to comply obd2(not an Arduino function - https://docs.microsoft.com/en-us/cpp/cpp/conditional-operator-q?view=vs-2017)
      sprintf_P(btdata2, PSTR("41 03 %02X 00\r\n>"), a);
    }
    else {
      sprintf_P(btdata2, PSTR("DATA ERROR\r\n>"));
    }
  }

  else if (!strcmp(btdata1, "0104")) { // engine load (%)
    if (dlcCommand(0x20, 0x05, 0x9c, 0x01, dlcdata)) {
      sprintf_P(btdata2, PSTR("41 04 %02X\r\n>"), dlcdata[2]);
    }
    else {
      sprintf_P(btdata2, PSTR("DATA ERROR\r\n>"));
    }
  }
  else if (!strcmp(btdata1, "0105")) { // ect (°C)
    if (dlcCommand(0x20, 0x05, 0x10, 0x01, dlcdata)) {
      float f = dlcdata[2];
      f = 155.04149 - f * 3.0414878 + pow(f, 2) * 0.03952185 - pow(f, 3) * 0.00029383913 + pow(f, 4) * 0.0000010792568 - pow(f, 5) * 0.0000000015618437;
      dlcdata[2] = round(f) + 40; // A-40
      sprintf_P(btdata2, PSTR("41 05 %02X\r\n>"), dlcdata[2]);
    }
    else {
      sprintf_P(btdata2, PSTR("DATA ERROR\r\n>"));
    }
  }
  else if (!strcmp(btdata1, "0106")) { // short FT (%)
    if (dlcCommand(0x20, 0x05, 0x20, 0x01, dlcdata)) {
      sprintf_P(btdata2, PSTR("41 06 %02X\r\n>"), dlcdata[2]);
    }
    else {
      sprintf_P(btdata2, PSTR("DATA ERROR\r\n>"));
    }
  }
  else if (!strcmp(btdata1, "0107")) { // long FT (%)
    if (dlcCommand(0x20, 0x05, 0x22, 0x01, dlcdata)) {
      sprintf_P(btdata2, PSTR("41 07 %02X\r\n>"), dlcdata[2]);
    }
    else {
      sprintf_P(btdata2, PSTR("DATA ERROR\r\n>"));
    }
  }
  //else if (!strcmp(data, "010A")) { // fuel pressure
  //  btSerial.print("41 0A EF\r\n");
  //}
  else if (!strcmp(btdata1, "010B")) { // map (kPa)
    if (dlcCommand(0x20, 0x05, 0x12, 0x01, dlcdata)) {
      sprintf_P(btdata2, PSTR("41 0B %02X\r\n>"), dlcdata[2]);
    }
    else {
      sprintf_P(btdata2, PSTR("DATA ERROR\r\n>"));
    }
  }
//  else if (!strcmp(btdata1, "010C")) { // rpm
//    if (dlcCommand(0x20, 0x05, 0x00, 0x02, dlcdata)) {
//      sprintf_P(btdata2, PSTR("41 0C %02X %02X\r\n>"), dlcdata[2], dlcdata[3]);
//    }
//    else {
//      sprintf_P(btdata2, PSTR("DATA ERROR\r\n>"));
//    }
//  }

//Engine RPM PID - Two bytes
  else if (!strcmp(btdata1, "010C")) { // rpm
    if (dlcCommand(0x20, 0x05, 0x00, 0x02, dlcdata)) {   //Note 2 bytes used here
        if ((dlcdata[2] == 255) && (dlcdata[3] == 255)) {   //Trap a condition where my test ECU sends 255, 255 when engine is off
            dlcdata[2]=0;                                   //Set a 255 value to 0
            dlcdata[3]=0;
        }
        sprintf_P(btdata2, PSTR("41 0C %02X %02X\r\n>"), dlcdata[2], dlcdata[3]);
    }
    else {
      sprintf_P(btdata2, PSTR("DATA ERROR\r\n>"));
    }
  }
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
rubensx, 2021-04-01:
hi Phillip, I'm stuck here =( can't solve the RPM

kerpz, 2021-04-01:
> hi Phillip, I'm stuck here =( can't solve the RPM

hi rubensx, found the issue hobd_elm use the obd2 algo

`  else if (!strcmp(btdata1, "010C")) { // rpm
    if (dlcCommand(0x20, 0x05, 0x00, 0x02, dlcdata)) {
      //sprintf_P(btdata2, PSTR("41 0C %02X %02X\r\n>"), dlcdata[2], dlcdata[3]);
     int rpm = (1875000 / (dlcdata[2] * 256 + dlcdata[3] + 1)) * 4;
     if (rpm < 0) { rpm = 0; }
     sprintf_P(btdata2, PSTR("41 0C %02X %02X\r\n>"), highByte(rpm), lowByte(rpm)); //((A*256)+B)/4
    }
    else {
      sprintf_P(btdata2, PSTR("DATA ERROR\r\n>"));
    }
  }`

you need to replace that with

rubensx, 2021-04-03:
hi Philip!! awesome!! works great!!! but  when engine is off the rpm goes to 17000 he he he, but solved on engine running... hey you have see this ? (hondash) ? has some features more (and I guess is the same project here)

Closed 2021-05-30.

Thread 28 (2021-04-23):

help with translate honda code ECT to a number

rubensx, 2021-04-23:
Hi Philip! how are you?

I came here because I had no one who know too much about honda code and maybe you can help
I'm in a project (a TFT ECT ring meter) to solve a S2000 AP2 2007+ problem (this cluster has a rocket science method to see ECT and need a CAN bus decode... yep forget this CAN and I'm creating a external temperature gauge).

Ok, using a ESP32 and a FTF 3.2" screen we can get a nice ring meter to place over the AP2 (with the same design) but I need to get a ECT value as a decimal value...

Looking your code I guess can use only ECT data to do that... (maybe you ask me about use a termopar k sensor or read the ECT gauge sensor from D16Z6, but the wire length and the engine temperature and RF interference is so bad to a simple arduino. So, I'm thinking about convert from 3 pin DLC information directly to my gauge (maybe a VTEC information too).

Can you take me to a "north" about this?

Thank you again (if you want to see this project I can show you the ring code images about)

rubensx, 2021-04-23:
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

Maybe a strange solution but...

mr-sneezy, 2021-04-24:
I'm not Philip, but I do have half of his original code in my branch of his project, on an S2K AP1.

If the 2007+ S2K is CAN bus then I'd buy a CAN transceiver for the ESP32 and load up somebodies CAN sniffer code. It may not be that hard to workout the packet structure etc. I'm surprised there is not already a CAN project for Honda on Github.

On the other hand, if all you want is ECT and are going to splice onto the gauge sensor wire and read the voltage into the ESP32 ADC, it should work. You may need to run into a 1:2 voltage divider to not exceed 3.3V on the ADC input. I have found from experience you will need at least a 10uF filter capacitor on the ADC to get rid of EMI and other electrical noise (like with my own additional S2K oil pressure sensing).

If you want a sensor that you can glue to the engine or coolant hose that WILL work over the length of the car and be immune to noise go with the DS18B20 type. I have three of these on a single 1-wire bus on my S2K and it behaves perfectly. One goes right back to the differential.

rubensx, 2021-04-24:
Hi Sneeze!! Your work is awesome!

Yea I’m trying to use CAN bus but some problems:
1- my version of AP2 is 2007+ and the ECT are from a delta by oil temp - ambient temp and coolant... is much complex and need a entire S2000 to sniff CAN bus (I’m at Brazil and S2000 are extremely rare and his parts too)
2- I bought a used cluster and someone edit parts of this cluster and maybe affect the CAN transceiver and since the cluster are a receptor and not a sender os these messages, it’s impossible to discover the right messages
3- at last, about all this situation, using a ILI9431 TFT on a ESP32 (yes in my first tests using this board to sniff CAN and other tests), and create a bezel to put over the panel.

this idea not so much better but I think some future uses in this TFT like a VTEC light, turbo booster information ando some other info by a push button... but I need to up the stairs by the first stage! Need a ECT... in my desk using a IR thermo and mlx library working good... I’ll see this DS18B20 but if I use the information from ecu is more accurate and maybe use more ECU information from my auxiliary’s TFT in future
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

rubensx, 2021-04-24:
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

rubensx, 2021-04-24:
Is not finished and the TFT not centered and has a plastic protection but... the animation and react is perfect and in real world are better than the photos

mr-sneezy, 2021-04-25:
Nice work so far, what you need is an ECU and a dash loom from a wreck to make a test system.

rubensx, 2021-04-25:
Import to Brazil is too expensive and the cost don’t worth! In this case a nice way is a Fueltech FT550 with touchscreen in dashboard!

if you can help to decode dlc ECT to a decimal number is desirable

rubensx, 2021-04-25:
I'm using the OBD_UNO version and works great to see in android, but I need a function to enable ECT codes to send without a BT connection (send via serial).

`  else if (!strcmp(btdata1, "0105")) { // ect (°C)
    if (dlcCommand(0x20, 0x05, 0x10, 0x01, dlcdata)) {
      float f = dlcdata[2];
      f = 155.04149 - f * 3.0414878 + pow(f, 2) * 0.03952185 - pow(f, 3) * 0.00029383913 + pow(f, 4) * 0.0000010792568 - pow(f, 5) * 0.0000000015618437;
      dlcdata[2] = round(f) + 40; // A-40
      sprintf_P(btdata2, PSTR("41 05 %02X\r\n>"), dlcdata[2]);

      // Test monitor
      ECT = f; // ECT declared as a float above
      Serial.print(F("*ECT "));
      Serial.println(ECT);

    }
    else {
      sprintf_P(btdata2, PSTR("DATA ERROR\r\n>"));
    }`

But only can see the ECT decimal with bluetooth android logged

any idea to start sending this value to serial bt independent?

rubensx, 2021-04-26:
stuck here...

for a strange reason only the ELM_Bridge  works for me to conect my bluetooh android cell
My goals is:

- Create a dlc bridge who can take all informadion by the pids and send it for serial (a decimal numbers)
- with ESP32 i'll take this decimal numbers to show ECT and VTEC light
- if I can still use a bt ELM connection is awesome

At the moment, I only can send serial decimal numbers message when the cell BT is connected, and I need it independent...

some ideia about it?

marcus-1975, 2021-04-27:
Hi, I don't have time to be doing detailed coding descriptions as I'm busy with my own projects, but in short here is were I'd start. Start with cloning Philips HOBD-UNI code version, disable the calls to the bluetooth code by disabling checks for BT data available (so it then uses LCD code block), then add a serial.print command right after the ECT calculations, to output the ECT values each cycle to the UART (that you choose to setup). Crude but should work. The Arduino does know you don't have the LCD so it can bang away on those pins care free.
https://www.arduino.cc/reference/en/language/functions/communication/serial/print/

Good luck with the project, you will learn a lot.

mr-sneezy, 2021-04-27:
Hi, I don't have time to be doing detailed coding descriptions as I'm busy with my own projects, but in short here is were I'd start. Start with cloning Philips HOBD-UNI code version, disable the calls to the bluetooth code by disabling checks for BT data available (so it then uses LCD code block), then add a serial.print command right after the ECT calculations, to output the ECT values each cycle to the UART (that you choose to setup). Crude but should work. The Arduino does know you don't have the LCD so it can bang away on those pins care free.
https://www.arduino.cc/reference/en/language/functions/communication/serial/print/

Good luck with the project, you will learn a lot.

rubensx, 2021-04-27:
Thank you Martin! Yesterday I’m using this solution (LCD version)!

In fact I’m trying to maintain Bluetooth connection to have a 2 options (a ECT for the s2000 panel and if I need a troubleshooting, using a torque app) but is more complex and I’ll test!

For some strange reason no other code from you and Philip work in my car a civic ej1!

when I open a torque app, this never “found a protocol” only a obd_elm bridge or obd_uno works...

the protocol handshake betwen other versions seems different (maybe the choose of obd1/obd2) and don’t work at all...

thank you for the north and I’m still trying something to include all functions and at last I will post the result

cheers!!

kerpz, 2021-04-30:
Hi guys, awesome work you got there. I've been busy with my new work so I haven't had time to tinker with this project. If you don't want to decode or read CAN bus I think you can read the sensor signal directly. I've done it before and derived the code from mpguino, so it's a standalone system reading speedometer, ect, rpm, injectors, etc. I'm not sure on where or what hard drive did I stored the codes. :)

rubensx, 2021-04-30:
Hi Philip!! How are you! Wow new work is exciting!! Go ahed!!

if you find rhis work and have a ECT values makes my life much more easy! If you can at this time! If this code are in internet maybe I can find in google maybe?

thank you

Closed 2021-05-30.

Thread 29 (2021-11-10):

Hey! new here

KrunoslavKrainovic, 2021-11-10:
Is there any documentation how to make everything works? i have arduino uno and lcd screen and i have ectune rom on my ecu, how can i get data from ecu? I want to make for my self digital dashboard but i dont know how to request data from ecu, if anyone would help it would be awesome

rubensx, 2023-01-01:
your ECU don't have DLC codes out from 3 pin data link plug anymore. Since you modded your ecu, the datalogger has a specific protocol and you can see over bluetooth wiring the module as is: https://www.burton-racing.com/products/bluetooth-datalogger

Closed 2023-03-20.

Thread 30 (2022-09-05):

Throttle inverse on obd1

rubensx, 2022-09-05:
hi kerps!

I can't figure out about my Throttle appers inverse (from 100% to 0) in bluetooth mode linked into Torque app. At the LCD all data are ok!

Can you help?

is a P28 ECU d16z6

thank you

kerpz, 2022-09-06:
Hi Ruben, try to set the obd mode to obd1.

rubensx, 2022-09-06:
I'll try, but P28 ECU are OBD1 the handshake will match?

rubensx, 2022-09-06:
[https://cdn2.solojavirtual.com/loja/arquivos_loja/59350/Fotos/thumbs3/produto_Foto2_12176017.png?cache=](url)

I'm using a arduino mega pro and a i2c oled to put all in clock set into a EJ1 (coupe 1995). I have do some changes into code for fit in this project!

rubensx, 2022-09-07:
hi Kerps!

I'm back!
I do a mistake! it's a R throttle dial in torque is show inverse! But I can't set to obd2 intead obd1!

but I test other files like the obd_elm and others and another doubt:

```
   else if (!strcmp(btdata1, "0145")) { // iacv / relative throttle position
    if (dlcCommand(0x20, 0x05, 0x28, 0x01, dlcdata)) {
      sprintf_P(btdata2, PSTR("41 45 %02X\r\n>"), dlcdata[2]);
    }
    else {
      sprintf_P(btdata2, PSTR("DATA ERROR\r\n>"));
    }
  }
  else if (!strcmp(btdata1, "2008")) { // custom hobd mapping / flags
    if (dlcCommand(0x20, 0x05, 0x08, 0x01, dlcdata)) {
      sprintf_P(btdata2, PSTR("60 08 %02X\r\n>"), dlcdata[2]);
    }
    else {
      sprintf_P(btdata2, PSTR("NO DATA\r\n>"));
    }
  }
  else if (!strcmp(btdata1, "200B")) { // custom hobd mapping / flags
    //sprintf_P(btdata2, PSTR("60 0C AA\r\n>")); // 10101010 / test data
    if (dlcCommand(0x20, 0x05, 0x0B, 0x01, dlcdata)) {
      sprintf_P(btdata2, PSTR("60 0B %02X\r\n>"), dlcdata[2]);
    }
    else {
      sprintf_P(btdata2, PSTR("NO DATA\r\n>"));
    }
  }
  else if (!strcmp(btdata1, "200C")) { // custom hobd mapping / flags
    if (dlcCommand(0x20, 0x05, 0x0C, 0x01, dlcdata)) {
      sprintf_P(btdata2, PSTR("60 0C %02X\r\n>"), dlcdata[2]);
    }
    else {
      sprintf_P(btdata2, PSTR("NO DATA\r\n>"));
    }
  }
  else if (!strcmp(btdata1, "200F")) { // custom hobd mapping / flags
    if (dlcCommand(0x20, 0x05, 0x0F, 0x01, dlcdata)) {
      sprintf_P(btdata2, PSTR("60 0F %02X\r\n>"), dlcdata[2]);
    }
    else {
      sprintf_P(btdata2, PSTR("NO DATA\r\n>"));
    }
  }

 //Custom PID for IACV position (Idle Air Control Valve opening) From HOPE
  else if (!strcmp(btdata1, "2004")) { // IACV position value (scaled to % by Torque app)
    if (dlcCommand(0x20, 0x05, 0x28, 0x01, dlcdata)) {
    sprintf_P(btdata2, PSTR("60 04 %02X\r\n>"), dlcdata[2]);
    }
    else {
      sprintf_P(btdata2, PSTR("DATA ERROR\r\n>"));
    }
  }
```

at the code above you put a 4 digit 2004 (as a example) to the custom pids, but in new version you create anbother way to identifi with only 2 digits. May this not clear to me ho you change the pid 0145 to the 2004 identify in obd_uni2 file?

```
          }
          else if (strstr(&btdata1[2], "42")) { // ecu voltage (V)
            if (dlcCommand(0x20, 0x05, 0x17, 0x01)) {
              float f = dlcdata[2];
              f = f / 10.45;
              unsigned int u = f * 1000; // ((A*256)+B)/1000
              sprintf_P(btdata2, PSTR("41 42 %02X %02X\r\n>"), highByte(u), lowByte(u));
            }
          }
          else if (strstr(&btdata1[2], "45")) { // iacv / relative throttle position (%)
            if (dlcCommand(0x20, 0x05, 0x28, 0x01)) {
              sprintf_P(btdata2, PSTR("41 45 %02X\r\n>"), dlcdata[2]);
            }
          }
        }
```

like this? Because I don't get clue how you know if the first 2 digits are 01 or 20!

That's I say because the obd_elm works great in P28 ecu with custom pids, but with new version some information are missing!

thank you again for your assistance and work

rubensx, 2022-09-07:
more tests:

with your custom PIDs file in torque folder, all changes runs like charm! Maybe my problem is, in LCD TPS = "-6" and in torque app the TPS are 98%, when I hit the gas slowly, became to 100% and runs to 0, 1, 2 ,3 ,4% (like the scale are looping and don't show negative scale in torque... weird)

rubensx, 2022-09-07:
How I can contribute with you to test or help?

kerpz, 2022-09-13:
Hi @rubensx sorry been busy lately, thanks for bringing that up I will check and compare it with the code that I'm using.

kerpz, 2022-09-19:
Hi @rubensx fixed applied to hobd_uni2, corrected the PID mapping for relative tps and iacv. I cannot test it at the moment my car is currently being restored.

rubensx, 2022-09-20:
Great! I’ll test for you in my “scanner” and I’ll back with feedback!

rubensx, 2022-09-21:
Hi @kerpz I'm using your sketch without any extra sensors, much like "hondash" and scanner only. So, in my tests with hc06 bt and arduino uno (buzzer and button present). So I need to edit some data, but now with last sketch in obd1 the bluetooth connect but TORQUE never found the handshake to ecu.

mix the code using only your TPS and IACV edit to old code, bt connect and running but tps and iacv are dead

kerpz, 2022-09-22:
Hi @rubensx  the hc06 has different baudrate 38400 if I remember it correctly.

kerpz, 2022-09-22:
Hi @rubensx  what code are you using? hc06 has 38400 baudrate by default.

rubensx, 2022-09-22:
My Hc06 works on 9600 (don't work in 38400),

Your newer code don't handshake the ecu protocol, and my code is slightly modified to exclude all extra sensors only has a LCD and a button

```
/*
 Author:
 - Philip Bordado (kerpz@yahoo.com)

 Hardware:
 - Arduino Nano (Compatible board)
 - HC-05 Bluetooth module
 - Resistors 680k ohms and 220k ohms
 - Piezo Buzzer
 - LCD 16x2 I2C
 Optional:
 - 100 psi transducer for fuel pressure (0.5v - 4.5v)
 - AEM AFR UEGO
 - 10K NTC Thermistor

 Software:
 - Arduino 1.8.19 (Stable)
 - SoftwareSerialWithHalfDuplex (Library)
   https://github.com/nickstedman/SoftwareSerialWithHalfDuplex

 Formula:
 - IMAP = RPM * MAP / IAT / 2
 - MAF = (IMAP/60)*(VE/100)*(Eng Disp)*(MMA)/(R)
   Where: VE = 80% (Volumetric Efficiency), R = 8.314 J/°K/mole, MMA = 28.97 g/mole (Molecular mass of air)
   http://www.lightner.net/obd2guru/IMAP_AFcalc.html
   http://www.installuniversity.com/install_university/installu_articles/volumetric_efficiency/ve_computation_9.012000.htm

 Arduino Pin Mapping / Configuration:
 * Pulse Input - 50k ohms over 5.1v zener
 $ Switch Out - 1k ohms on NPN transistor (2n3904)

 - 00 = Serial RX
 - 01 = Serial TX
 - 02 = * Injector Input
 - 03 = * Injector Input
 - 04 = $ Door Lock | * RPM Input
 - 05 = $ Door Unlock | * VSS Input
 - 06 = $ AC Compressor
 - 07 =
 - 08 = * Door Sensor
 - 09 = AEM AFR UEGO (Serial In)
 - 10 = Bluetooth RX
 - 11 = Bluetooth TX
 - 12 = K-Line (Serial In)
 - 13 = Piezo buzzer (+)

 - 14 = (A0) Voltage divider (Input Signal)
 - 15 = (A1) 100 PSI Fuel Pressure
 - 16 = (A2) AEM AFR UEGO (ADC)
 - 17 = (A3) NTC Thermistor
 - 18 = (A4) I2C / LCD I2C
 - 19 = (A5) I2C / LCD I2C
 - 20 = (A6) Navigation Button (reason: multiple button using resistors)
 - 21 = (A7)
*/

#define APPNAME " Honda OBD v1.0" // 16 chars

#include <EEPROM.h>

// OUT
//#define PIN_LOCK 4
//#define PIN_UNLOCK 5
//#define PIN_AC 6
#define PIN_BUZZER 13
// IN
//#define PIN_DOOR 8
//#define PIN_VOLT 14
//#define PIN_FP 15
//#define PIN_AFR 16
//#define PIN_TH 17
#define PIN_BUTTON 9

#include <LiquidCrystal_I2C.h>
//LiquidCrystal_I2C lcd(0x27, 16, 2);
LiquidCrystal_I2C lcd(0x3f, 2, 1, 0, 4, 5, 6, 7);

// comment the PCINT1_vect,PCINT2_vect,PCINT3_vect handle in softserial library
// since we are just using D10,D11,D12 and we want to handle interrupts @ A0 - A5
// PCINT0_vect  // D8 - D13
// PCINT1_vect  // A0 - A5
// PCINT2_vect  // D0 - D7
// PCINT3_vect

#include <SoftwareSerialWithHalfDuplex.h>

SoftwareSerialWithHalfDuplex btSerial(10, 11); // RX, TX
SoftwareSerialWithHalfDuplex dlcSerial(12, 12, false, false);
//SoftwareSerialWithHalfDuplex aemSerial(9, 9, false, false);

bool elm_mode = false;
bool elm_memory = false;
bool elm_echo = false;
bool elm_space = true;
bool elm_linefeed = true;
bool elm_header = false;
byte elm_protocol = 0; // auto

// ecu data
int rpm=0, ect=0, iat=0,maps=0, baro=0, tps=0, volt=0, imap=0, sft=0, lft=0, inj=0, ign=0, lmt=0, iac=0, knoc=0;
// extra sensor data
float volt2,th,afr,fp;
bool cp;
int btn;

int rpmtop=0,volttop=0,mapstop=0,tpstop=0,ecttop=0,iattop=0;

unsigned long vsssum=0,running_time=0,idle_time=0,distance=0;
byte vss=0,vsstop=0,vssavg=0;

byte obd_select = 1; // 1 = obd1, 2 = obd2
byte pag_select = 0; // lcd page

byte ect_alarm = 98; // celcius
byte vss_alarm = 100; // kph
byte th_threshold = 4; // celcius / + 10

bool isButtonPressed = false;

// voltage divider
//float R1 = 30000.0;
//float R2 = 7500.0;
//float R1 = 680000.0; // Resistance of R1 (680kohms)
//float R2 = 220000.0; // Resistance of R2 (220kohms)
//float R3 = 10000.0; // Thermistor divider

unsigned long err_timeout = 0, err_checksum = 0, ect_cnt = 0, vss_cnt = 0;

byte dlcdata[20] = {0};  // dlc data buffer

int dtcErrors[14], dtcCount = 0;

void bt_write(char *str) {
  char c = *str;
  while (*str != '\0') {
    if (!elm_linefeed && *str == 10) *str++; // skip linefeed for all reply
    if (c == '4' && !elm_space && *str == 32) *str++; // skip space for obd reply
    btSerial.write(*str++);
  }
}

void dlcInit() {
  dlcSerial.write(0x68);
  dlcSerial.write(0x6a);
  dlcSerial.write(0xf5);
  dlcSerial.write(0xaf);
  dlcSerial.write(0xbf);
  dlcSerial.write(0xb3);
  dlcSerial.write(0xb2);
  dlcSerial.write(0xc1);
  dlcSerial.write(0xdb);
  dlcSerial.write(0xb3);
  dlcSerial.write(0xe9);
  delay(300);
}

int dlcCommand(byte cmd, byte num, byte loc, byte len) {
  byte crc = (0xFF - (cmd + num + loc + len - 0x01)); // checksum FF - (cmd + num + loc + len - 0x01)

  unsigned long timeOut = millis() + 200; // timeout @ 200 ms

  memset(dlcdata, 0, sizeof(dlcdata));

  dlcSerial.listen();

  dlcSerial.write(cmd);  // header/cmd read memory ??
  dlcSerial.write(num);  // num of bytes to send
  dlcSerial.write(loc);  // address
  dlcSerial.write(len);  // num of bytes to read
  dlcSerial.write(crc);  // checksum

  int i = 0;
  while (i < (len+3) && millis() < timeOut) {
    if (dlcSerial.available()) {
      dlcdata[i] = dlcSerial.read();
      //delay(1); // this is required
      i++;
    }
  }

  if (i < (len+3)) { // timeout
    err_timeout++;
    return 0;  // data error
  }
  // checksum
  crc = 0;
  for (i=0; i<len+2; i++) {
    crc = crc + dlcdata[i];
  }
  crc = 0xFF - (crc - 1);
  if (crc != dlcdata[len+2]) { // checksum failed
    err_checksum++;
    return 0; // data error
  }
  return 1; // success
}

long readVcc()
{
  // Read 1.1V reference against AVcc
  // set the reference to Vcc and the measurement to the internal 1.1V reference
  #if defined(__AVR_ATmega32U4__) || defined(__AVR_ATmega1280__) || defined(__AVR_ATmega2560__)
    ADMUX = _BV(REFS0) | _BV(MUX4) | _BV(MUX3) | _BV(MUX2) | _BV(MUX1);
  #elif defined (__AVR_ATtiny24__) || defined(__AVR_ATtiny44__) || defined(__AVR_ATtiny84__)
    ADMUX = _BV(MUX5) | _BV(MUX0);
  #elif defined (__AVR_ATtiny25__) || defined(__AVR_ATtiny45__) || defined(__AVR_ATtiny85__)
    ADMUX = _BV(MUX3) | _BV(MUX2);
  #else
    ADMUX = _BV(REFS0) | _BV(MUX3) | _BV(MUX2) | _BV(MUX1);
  #endif

  delay(2); // Wait for Vref to settle
  ADCSRA |= _BV(ADSC); // Start conversion
  while (bit_is_set(ADCSRA,ADSC)); // measuring

  uint8_t low  = ADCL; // must read ADCL first - it then locks ADCH
  uint8_t high = ADCH; // unlocks both

  long vcc = (high<<8) | low;
  vcc = 1125300L / vcc; // Calculate Vcc (in mV); 1125300 = 1.1*1023*1000
  return vcc;
}

// bluetooth routines
void procbtSerial() {
    char btdata1[20]={0};  // bt data in buffer
    char btdata2[20]={0};  // bt data out buffer
    int i = 0;

    while (btSerial.available()) {
      btdata1[i] = toupper(btSerial.read());

      delay(1); // this is required

      if (btdata1[i] == '\r') { // terminate at \r
        btdata1[i] = '\0';
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

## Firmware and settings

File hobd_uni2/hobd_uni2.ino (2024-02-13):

/*
 Author:
 - Philip Bordado (kerpz@yahoo.com)

 Hardware:
 - Arduino Nano (Compatible board)
 - HC-05 Bluetooth module
 - Resistors 680k ohms and 220k ohms
 - Piezo Buzzer
 - LCD 16x2 I2C
 Optional:
 - 100 psi transducer for fuel pressure (0.5v - 4.5v)
 - AEM AFR UEGO
 - 10K NTC Thermistor

 Software:
 - Arduino 1.8.19 (Stable)
 - SoftwareSerialWithHalfDuplex (Library)
   https://github.com/nickstedman/SoftwareSerialWithHalfDuplex

 Formula:
 - IMAP = RPM * MAP / IAT / 2
 - MAF = (IMAP/60)*(VE/100)*(Eng Disp)*(MMA)/(R)
   Where: VE = 80% (Volumetric Efficiency), R = 8.314 J/°K/mole, MMA = 28.97 g/mole (Molecular mass of air)
   http://www.lightner.net/obd2guru/IMAP_AFcalc.html
   http://www.installuniversity.com/install_university/installu_articles/volumetric_efficiency/ve_computation_9.012000.htm
 - AFR = (o2 * 2) + 10
   Where: o2 in Volts

 Arduino Pin Mapping / Configuration:
 * Pulse Input - 50k ohms over 5.1v zener
 $ Switch Out - 1k ohms on NPN transistor (2n3904)

 - 00 = Serial RX
 - 01 = Serial TX
 - 02 = * Injector Input
 - 03 = * Injector Input
 - 04 = $ Door Lock | * RPM Input
 - 05 = $ Door Unlock | * VSS Input
 - 06 = $ AC Compressor
 - 07 = Navigation Button
 - 08 = * Door Sensor
 - 09 = AEM AFR UEGO (Serial In)
 - 10 = Bluetooth RX
 - 11 = Bluetooth TX
 - 12 = K-Line (Serial In)
 - 13 = Piezo buzzer (+)

 - 14 = (A0) Voltage divider (Input Signal)
 - 15 = (A1) 100 PSI Fuel Pressure
 - 16 = (A2) AEM AFR UEGO (ADC)
 - 17 = (A3) NTC Thermistor
 - 18 = (A4) I2C / LCD I2C
 - 19 = (A5) I2C / LCD I2C
 - 20 = (A6)
 - 21 = (A7)
*/

#define APPNAME "Honda UNI   v1.0" // 16 chars

#include <EEPROM.h>

// OUT
#define PIN_LOCK 4
#define PIN_UNLOCK 5
#define PIN_AC 6
#define PIN_BUZZER 13
// IN
#define PIN_BUTTON 7
#define PIN_DOOR 8
#define PIN_VOLT 14
#define PIN_FP 15
#define PIN_AFR 16
#define PIN_TH 17

#include <LiquidCrystal_I2C.h>
LiquidCrystal_I2C lcd(0x3f, 16, 2); // my car lcd = 0x3f, my bench lcd = 0x27

// comment the PCINT1_vect,PCINT2_vect,PCINT3_vect handle in softserial library
// since we are just using D10,D11,D12 and we want to handle interrupts @ A0 - A5
// PCINT0_vect  // D8 - D13
// PCINT1_vect  // A0 - A5
// PCINT2_vect  // D0 - D7
// PCINT3_vect

#include <SoftwareSerialWithHalfDuplex.h>

SoftwareSerialWithHalfDuplex btSerial(10, 11); // RX, TX
SoftwareSerialWithHalfDuplex dlcSerial(12, 12, false, false);
// SoftwareSerialWithHalfDuplex aemSerial(9, 9, false, false);

bool elm_mode = false;
bool elm_memory = false;
bool elm_echo = false;
bool elm_space = true;
bool elm_linefeed = true;
bool elm_header = false;
byte elm_protocol = 0; // auto

// ecu data
int rpm = 0, ect = 0, iat = 0, maps = 0, baro = 0, tps = 0, sft = 0, lft = 0, inj = 0, ign = 0, lmt = 0, iacv = 0, knoc = 0;
float volt = 0, o2 = 0;
byte vss = 0;
bool sw_aircon, sw_brake, sw_vtec;

// extra sensor
float volt2 = 0, th = 0, afr = 0, fp = 0;
bool cp;

int maf, rpmtop = 0, volttop = 0, mapstop = 0, tpstop = 0, ecttop = 0, iattop = 0;
unsigned long vsssum = 0, running_time = 0, idle_time = 0, distance = 0;
byte gear, vsstop = 0, vssavg = 0;

byte obd_select = 2; // 1 = obd1, 2 = obd2
byte pag_select = 1; // lcd page

byte ect_alarm = 98;   // celcius
byte vss_alarm = 100;  // kph / + 10
byte th_threshold = 4; // celcius / + 10

bool isButtonPressed = false;

// voltage divider
// float R1 = 30000.0;
// float R2 = 7500.0;
float R1 = 680000.0; // Resistance of R1 (680kohms)
float R2 = 220000.0; // Resistance of R2 (220kohms)
float R3 = 10000.0;  // Thermistor divider

byte dlcdata[20] = {0}; // dlc data buffer
byte dlcTimeout = 0, dlcChecksumError = 0;
bool dlcWait = false;

int dtcErrors[14], dtcCount = 0;

// --- begin ECU functions ---
void dlcInit()
{
  dlcSerial.write(0x68);
  dlcSerial.write(0x6a);
  dlcSerial.write(0xf5);
  dlcSerial.write(0xaf);
  dlcSerial.write(0xbf);
  dlcSerial.write(0xb3);
  dlcSerial.write(0xb2);
  dlcSerial.write(0xc1);
  dlcSerial.write(0xdb);
  dlcSerial.write(0xb3);
  dlcSerial.write(0xe9);
  delay(300);
}

int dlcCommand(byte cmd, byte num, byte loc, byte len)
{
  byte crc = (0xFF - (cmd + num + loc + len - 0x01)); // checksum FF - (cmd + num + loc + len - 0x01)

  unsigned long timeOut = millis() + 200; // timeout @ 200 ms

  memset(dlcdata, 0, sizeof(dlcdata));

  dlcSerial.listen();

  dlcSerial.write(cmd); // header/cmd read memory ??
  dlcSerial.write(num); // num of bytes to send
  dlcSerial.write(loc); // address
  dlcSerial.write(len); // num of bytes to read
  dlcSerial.write(crc); // checksum

  // reply: 00 len+3 data...
  int i = 0;
  while (i < (len + 3) && millis() < timeOut)
  {
    if (dlcSerial.available())
    {
      dlcdata[i] = dlcSerial.read();
      // if (dlcdata[i] != 0x00 && dlcdata[i+1] != (len+3)) continue; // ignore ?
      i++;
    }
  }

  if (i < (len + 3))
  { // timeout
    dlcTimeout++;
    if (dlcTimeout > 255)
      dlcTimeout = 0;
    return 0; // failed
  }

  // checksum
  crc = 0;
  for (i = 0; i < len + 2; i++)
  {
    crc = crc + dlcdata[i];
  }
  crc = 0xFF - (crc - 1);
  if (crc != dlcdata[len + 2])
  { // checksum failed
    dlcChecksumError++;
    if (dlcChecksumError > 255)
      dlcChecksumError = 0;
    return 0; // failed
  }

  return 1; // success
}

// Read DTC Error
void scanDtcError()
{
  byte i;

  if (dlcCommand(0x20, 0x05, 0x40, 0x10))
  { // row 5
    for (i = 0; i < 14; i++)
    {
      if (dlcdata[i + 2] >> 4)
      {
        dtcErrors[i] = i * 2;
        dtcCount++;
      }
      if (dlcdata[i + 2] & 0xf)
      {
        // haxx
        // if (errnum == 23) errnum = 22;
        // if (errnum == 24) errnum = 23;
        dtcErrors[i] = (i * 2) + 1;
        // haxx
        if (dtcErrors[i] == 23)
          dtcErrors[i] = 22;
        if (dtcErrors[i] == 24)
          dtcErrors[i] = 23;
        dtcCount++;
      }
    }
    pag_select = 3;
  }
}

// Reset ECU
void resetEcu()
{
  // 21 04 01 DA / 01 03 FC
  dlcCommand(0x21, 0x04, 0x01, 0x00); // reset ecu
}

// Read ECU Data
void readEcuData()
{
  float f;

  // char h_initobd2[12] = {0x68,0x6a,0xf5,0xaf,0xbf,0xb3,0xb2,0xc1,0xdb,0xb3,0xe9}; // 200ms - 300ms delay
  // byte h_cmd1[6] = {0x20,0x05,0x00,0x10,0xcb}; // row 1
  // byte h_cmd2[6] = {0x20,0x05,0x10,0x10,0xbb}; // row 2
  // byte h_cmd3[6] = {0x20,0x05,0x20,0x10,0xab}; // row 3
  // byte h_cmd4[6] = {0x20,0x05,0x76,0x0a,0x5b}; // ecu id

  if (dlcCommand(0x20, 0x05, 0x00, 0x10))
  { // row 1
    if (obd_select == 1)
      rpm = 1875000 / (dlcdata[2] * 256 + dlcdata[3] + 1); // OBD1
    if (obd_select == 2)
      rpm = (dlcdata[2] * 256 + dlcdata[3]) / 4; // OBD2
    // in odb1 rpm is -1
    if (rpm < 0)
    {
      rpm = 0;
    }

    vss = dlcdata[4];

    // discrete sensors
    // dlcdata[10]
    sw_aircon = bitRead(dlcdata[10], 2);
    // dlcdata[11]
    // dlcdata[12]
    sw_vtec = bitRead(dlcdata[12], 3);
    // dlcdata[13]
    // dlcdata[14]
    // dlcdata[15]
    // dlcdata[17]
  }

  delay(1);

  if (dlcCommand(0x20, 0x05, 0x10, 0x10))
  { // row2
    f = dlcdata[2];
    ect = 155.04149 - f * 3.0414878 + pow(f, 2) * 0.03952185 - pow(f, 3) * 0.00029383913 + pow(f, 4) * 0.0000010792568 - pow(f, 5) * 0.0000000015618437;
    f = dlcdata[3];
    iat = 155.04149 - f * 3.0414878 + pow(f, 2) * 0.03952185 - pow(f, 3) * 0.00029383913 + pow(f, 4) * 0.0000010792568 - pow(f, 5) * 0.0000000015618437;
    maps = dlcdata[4] * 0.716 - 5; // 101 kPa @ off|wot // 10kPa - 30kPa @ idle
    baro = dlcdata[5] * 0.716 - 5; // kPa
    tps = (dlcdata[6] - 24) / 2;

    f = dlcdata[7];
    o2 = f / 51.3; // (V) o2

    /*
    // 0v to 1v / stock sensor
    // 0v to 5v / AEM UEGO / linear
    afr = (f * 2) + 10; // afr for AEM UEGO
    */

    f = dlcdata[9];
    volt = f / 10.45; // (V) battery
    // alt_fr = dlcdata[10] / 2.55 // (%) alternator load
    // eld = 77.06 - dlcdata[11] / 2.5371; // (Amps) electrical load
  }

  delay(1);

  if (dlcCommand(0x20, 0x05, 0x20, 0x10))
  {                                     // row3
    sft = (dlcdata[2] / 128 - 1) * 100; // (%) -30 to 30
    lft = (dlcdata[3] / 128 - 1) * 100; // (%) -30 to 30

    inj = (dlcdata[6] * 256 + dlcdata[7]) / 250; // (ms) 0 to 16

    // ign = (dlcdata[8] - 128) / 2;
    f = dlcdata[8];
    ign = (f - 24) / 4; // (degrees)

    // lmt = (dlcdata[9] - 128) / 2;
    f = dlcdata[9];
    lmt = (f - 24) / 4;

    iacv = dlcdata[10] / 2.55;
  }

  delay(1);

  if (dlcCommand(0x20, 0x05, 0x30, 0x10))
  { // row4
    // dlcdata[7] to dlcdata[12] unknown
    knoc = dlcdata[14] / 51; // 0 to 5
  }
}
// --- end ECU functions ---

void pushPinHi(byte pin, unsigned int delayms)
{
  digitalWrite(pin, HIGH);
  delay(delayms);
  digitalWrite(pin, LOW);
}

// --- begin extra sensors ---
long readVcc()
{
// Read 1.1V reference against AVcc
// set the reference to Vcc and the measurement to the internal 1.1V reference
#if defined(__AVR_ATmega32U4__) || defined(__AVR_ATmega1280__) || defined(__AVR_ATmega2560__)
  ADMUX = _BV(REFS0) | _BV(MUX4) | _BV(MUX3) | _BV(MUX2) | _BV(MUX1);
#elif defined(__AVR_ATtiny24__) || defined(__AVR_ATtiny44__) || defined(__AVR_ATtiny84__)
  ADMUX = _BV(MUX5) | _BV(MUX0);
#elif defined(__AVR_ATtiny25__) || defined(__AVR_ATtiny45__) || defined(__AVR_ATtiny85__)
  ADMUX = _BV(MUX3) | _BV(MUX2);
#else
  ADMUX = _BV(REFS0) | _BV(MUX3) | _BV(MUX2) | _BV(MUX1);
#endif

  delay(2);            // Wait for Vref to settle
  ADCSRA |= _BV(ADSC); // Start conversion
  while (bit_is_set(ADCSRA, ADSC))
    ; // measuring

  uint8_t low = ADCL;  // must read ADCL first - it then locks ADCH
  uint8_t high = ADCH; // unlocks both

  long vcc = (high << 8) | low;
  vcc = 1125300L / vcc; // Calculate Vcc (in mV); 1125300 = 1.1*1023*1000
  return vcc;
}

float readVoltage()
{
  float f;

  // read voltage sensor (volt2)
  f = readVcc() / 1000;                    // V read from ref. or 5.0
  f = (analogRead(PIN_VOLT) * f) / 1024.0; // V
  f = f / (R2 / (R1 + R2));                // voltage divider

  return f;
}

float readAirFuelRatio()
{
  // air fuel ratio, x=afr(10-20), y=volts(0-5)
  // y = mx + b // slope intercept
  // x = (y - b) / m // derived for x
  // m = y2 - y1 / x2 - x1 = 0.5
  // y = 0.5x + 0 @ x = 10, b = -5

  // where:
  // y = volts
  // m = slope
  // b = y intercept
  // x = afr

  // x = (y + 5) / 0.5

  // read afr sensor (afr)
  float f = readVcc() / 1000;             // V read from ref. or 5.0
  f = (analogRead(PIN_AFR) * f) / 1024.0; // V
  f = (f + 5) / 0.5;                      // afr
  // f = 2 * f + 10;

  return f;
}

float readThermistor()
{
  // read thermal sensor (th)
  int b = 3950;
  float f = analogRead(PIN_TH);

  f = R3 * (1023.0 / f - 1.0);
  f = log(f);
  f = 1.0 / (0.001129148 + (0.000234125 * f) + (0.0000000876741 * f * f * f)); // K
  f = f - 273.15;                                                              // convert to C
  // ideal temperature correctors
  if (f < 0)
    f = 0;
  if (f > 99)
    f = 99;

  /*
  f = 1023.0 / f  - 1.0;
  f = R3 / f;                 // resistance
  // th steinhart;
  f = f / 10000.0;            // (R/Ro)
  f = log(f);                 // ln(R/Ro)
  f /= b;                     // 1/B * ln(R/Ro)
  f += 1.0 / (25 + 273.15);   // + (1/To)
  f = 1.0 / f;                // Invert
  f -= 273.15;                // convert to C
  */

  return f;
}

float readFuelPressure()
{
  // fuel pressure, x=psi(0-100), y=volts(0.5-4.5)
  // y = mx + b
  // x = (y - b) / m // derived for x
  // m = y2 - y1 / x2 - x1 = 0.04
  // y = 0.04x + 0.5 @ x = 0, b = -5

  // where:
  // y = volts
  // m = slope
  // b = y intercept
  // x = psi

  // x = (y - 0.5) / 0.04

  // fuel pressur sensor (fp)
  float f = readVcc() / 1000;            // V read from ref. or 5.0
  f = (analogRead(PIN_FP) * f) / 1024.0; // V
  f = (f - 0.5) / 0.04;                  // psi
  f = f * 6.89476;                       // kPa
  // ideal temperature correctors
  if (f < 0)
    f = 0;
  if (f > 689)
    f = 689;

  return f;
}
// --- end extra sensors ---

// --- begin bluetooth serial functions ---
void bt_write(char *str)
{
  char c = *str;
  while (*str != '\0')
  {
    if (!elm_linefeed && *str == 10)
      *str++; // skip linefeed for all reply
    if (c == '4' && !elm_space && *str == 32)
      *str++; // skip space for obd reply
    btSerial.write(*str++);
  }
}

void procbtSerial()
{
  char btdata1[20] = {0}; // bt data in buffer
  char btdata2[20] = {0}; // bt data out buffer
  int i = 0;

  btSerial.listen();

  while (btSerial.available())
  {
    btdata1[i] = toupper(btSerial.read());
    // Serial.print(btdata1[i]);
    delay(1); // this is required

    if (btdata1[i] == '\r')
    { // terminate at \r
      btdata1[i] = '\0';

      // byte len = strlen(btdata1);
      if (!strcmp(btdata1, "ATD"))
      { // defaults
        elm_echo = false;
        elm_space = true;
        elm_linefeed = true;
        elm_header = false;
        sprintf_P(btdata2, PSTR("OK\r\n>"));
      }
      else if (!strcmp(btdata1, "ATI"))
      { // print id / general
        sprintf_P(btdata2, "%s\r\n>", APPNAME);
      }
      else if (!strcmp(btdata1, "ATZ"))
      { // reset all / general
        elm_echo = false;
        elm_space = true;
        elm_linefeed = true;
        elm_header = false;
        sprintf_P(btdata2, "%s\r\n>", APPNAME);
      }
      else if (i == 4 && strstr(btdata1, "ATE"))
      { // echo on/off / general
        elm_echo = (btdata1[3] == '1' ? true : false);
        sprintf_P(btdata2, PSTR("OK\r\n>"));
      }
      else if (i == 4 && strstr(btdata1, "ATL"))
      { // linfeed on/off / general
        elm_linefeed = (btdata1[3] == '1' ? true : false);
        sprintf_P(btdata2, PSTR("OK\r\n>"));
      }
      else if (i == 4 && strstr(btdata1, "ATM"))
      { // memory on/off / general
        // elm_memory = (btdata1[3] == '1' ? true : false);
        sprintf_P(btdata2, PSTR("OK\r\n>"));
      }
      else if (i == 4 && strstr(btdata1, "ATS"))
      { // space on/off / obd
        elm_space = (btdata1[3] == '1' ? true : false);
        sprintf_P(btdata2, PSTR("OK\r\n>"));
      }
      else if (i == 4 && strstr(btdata1, "ATH"))
      { // headers on/off / obd
        // elm_header = (btdata1[3] == '1' ? true : false);
        sprintf_P(btdata2, PSTR("OK\r\n>"));
      }
      else if (i == 5 && strstr(btdata1, "ATSP"))
      { // set protocol to ? and save it / obd
        // elm_protocol = atoi(btdata1[4]);
        sprintf_P(btdata2, PSTR("OK\r\n>"));
      }
      else if (!strcmp(btdata1, "ATDP"))
      { // display protocol / obd
        sprintf_P(btdata2, PSTR("AUTO\r\n>"));
      }
      else if (!strcmp(btdata1, "ATRV"))
      { // read voltage in float / volts
        // btSerial.print("12.0V\r\n>");
        volt2 = readVoltage();
        sprintf_P(btdata2, PSTR("%.1fV\r\n>"), volt2);
      }
      // kerpz custom AT cmd
      else if (i == 6 && strstr(btdata1, "ATSHP"))
      { // set hobd protocol
        if (btdata1[5] == '1')
        {
          obd_select = 1;
        }
        if (btdata1[5] == '2')
        {
          obd_select = 2;
        }
        EEPROM.write(0, obd_select);
        sprintf_P(btdata2, PSTR("OK\r\n>"));
      }
      else if (!strcmp(btdata1, "ATDHP"))
      { // display hobd protocol
        sprintf_P(btdata2, PSTR("HOBD%d\r\n>"), obd_select);
      }
      else if (strstr(btdata1, "ATSAP"))
      { // set arduino pin value (1=hi,0=lo,T=toggle)
        byte pin = ((btdata1[5] > '9') ? (btdata1[5] & ~0x20) - 'A' + 10 : (btdata1[5] - '0') * 16) +
                   ((btdata1[6] > '9') ? (btdata1[6] & ~0x20) - 'A' + 10 : (btdata1[6] - '0'));
        if (btdata1[7] == 'T')
        {
          digitalWrite(pin, !digitalRead(pin));
        }
        else
        {
          digitalWrite(pin, btdata1[7]);
        }

        sprintf_P(btdata2, PSTR("OK\r\n>"));
      }
      else if (strstr(btdata1, "ATDAP"))
      { // display arduino pin value (1=hi,0=lo)
        byte pin = ((btdata1[5] > '9') ? (btdata1[5] & ~0x20) - 'A' + 10 : (btdata1[5] - '0') * 16) +
                   ((btdata1[6] > '9') ? (btdata1[6] & ~0x20) - 'A' + 10 : (btdata1[6] - '0'));
        sprintf_P(btdata2, PSTR("%d\r\n>"), digitalRead(pin));
      }
      else if (strstr(btdata1, "ATPAP"))
      { // push arduino pin high for 1sec // used for locking/unlocking door
        byte pin = ((btdata1[5] > '9') ? (btdata1[5] & ~0x20) - 'A' + 10 : (btdata1[5] - '0') * 16) +
                   ((btdata1[6] > '9') ? (btdata1[6] & ~0x20) - 'A' + 10 : (btdata1[6] - '0'));
        pushPinHi(pin, 1000);

        sprintf_P(btdata2, PSTR("OK\r\n>"));
      }
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
void loop()
{
  static unsigned long btTick = 0;

  procButtons();

  btSerial.listen();
  if (btSerial.available())
  {
    if (!elm_mode)
    {
      elm_mode = true;
      lcd.clear();
      lcd.setCursor(0, 0);
      lcd.print(" Bluetooth Mode");
      lcd.setCursor(0, 1);
      lcd.print(" ECU Type: OBD");
      lcd.print(obd_select);
    }
    procbtSerial();
    btTick = millis();
  }

  if (millis() - btTick >= 2000)
  { // bt timeout 2 secs
    elm_mode = false;
  }

  if (!elm_mode)
  {
    execEvery(250);
  }
}

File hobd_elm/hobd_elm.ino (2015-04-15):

/*
 Author:
 - Philip Bordado (kerpz@yahoo.com)
 Hardware:
 - HC-05 Bluetooth module at pin 10 (Rx) pin 11 (Tx) 
 - DLC(K-line) at pin 12
 Software:
 - Arduino 1.0.5
 - SoftwareSerialWithHalfDuplex
   https://github.com/nickstedman/SoftwareSerialWithHalfDuplex
   
 Formula:
 - IMAP = RPM * MAP / IAT / 2
 - MAF = (IMAP/60)*(VE/100)*(Eng Disp)*(MMA)/(R)
   Where: VE = 80% (Volumetric Efficiency), R = 8.314 J/°K/mole, MMA = 28.97 g/mole (Molecular mass of air)
   http://www.lightner.net/obd2guru/IMAP_AFcalc.html
   http://www.installuniversity.com/install_university/installu_articles/volumetric_efficiency/ve_computation_9.012000.htm
*/
#include <SoftwareSerialWithHalfDuplex.h>

SoftwareSerialWithHalfDuplex btSerial(10, 11); // RX, TX
SoftwareSerialWithHalfDuplex dlcSerial(12, 12, false, false);

bool elm_memory = false;
bool elm_echo = false;
bool elm_space = false;
bool elm_linefeed = false;
bool elm_header = false;
int  elm_protocol = 0; // auto

void bt_write(char *str) {
  while (*str != '\0')
    btSerial.write(*str++);
}

void dlcInit() {
  dlcSerial.write(0x68);
  dlcSerial.write(0x6a);
  dlcSerial.write(0xf5);
  dlcSerial.write(0xaf);
  dlcSerial.write(0xbf);
  dlcSerial.write(0xb3);
  dlcSerial.write(0xb2);
  dlcSerial.write(0xc1);
  dlcSerial.write(0xdb);
  dlcSerial.write(0xb3);
  dlcSerial.write(0xe9);
  delay(300);
}

int dlcCommand(byte cmd, byte num, byte loc, byte len, byte data[]) {
  byte crc = (0xFF - (cmd + num + loc + len - 0x01)); // checksum FF - (cmd + num + loc + len - 0x01)

  unsigned long timeOut = millis() + 250; // timeout @ 250 ms
  memset(data, 0, sizeof(data));

  dlcSerial.listen();

  dlcSerial.write(cmd);  // header/cmd read memory ??
  dlcSerial.write(num);  // num of bytes to send
  dlcSerial.write(loc);  // address
  dlcSerial.write(len);  // num of bytes to read
  dlcSerial.write(crc);  // checksum
  
  int i = 0;
  while (i < (len+3) && millis() < timeOut) {
    if (dlcSerial.available()) {
      data[i] = dlcSerial.read();
      i++;
    }
  }
  if (data[0] != 0x00 && data[1] != (len+3)) { // or use checksum?
    return 0; // error
  }
  if (i < (len+3)) { // timeout
    return 0; // error
  }
  return 1; // success
}

void procbtSerial(void) {
  char btdata1[20];  // bt data in buffer
  char btdata2[20];  // bt data out buffer
  byte dlcdata[20];  // dlc data buffer
  int i = 0;

  memset(btdata1, 0, sizeof(btdata1));
  while (i < 20)
  {
    if (btSerial.available()) {
      btdata1[i] = toupper(btSerial.read());
      if (btdata1[i] == '\r') { // terminate at \r
        btdata1[i] = '\0';
        break;
      }
      else if (btdata1[i] != ' ') { // ignore space
        ++i;
      }
    }
  }

  memset(btdata2, 0, sizeof(btdata2));

  if (!strcmp(btdata1, "ATD")) {
    sprintf_P(btdata2, PSTR("OK\r\n>"));
  }
  else if (!strcmp(btdata1, "ATI")) { // print id / general
    sprintf_P(btdata2, PSTR("HOBD v1.0\r\n>"));
  }
  else if (!strcmp(btdata1, "ATZ")) { // reset all / general
    sprintf_P(btdata2, PSTR("HOBD v1.0\r\n>"));
  }
  else if (strstr(btdata1, "ATE")) { // echo on/off / general
    elm_echo = (btdata1[3] == '1' ? true : false);
    sprintf_P(btdata2, PSTR("OK\r\n>"));
  }
  else if (strstr(btdata1, "ATL")) { // linfeed on/off / general
    elm_linefeed = (btdata1[3] == '1' ? true : false);
    sprintf_P(btdata2, PSTR("OK\r\n>"));
  }
  else if (strstr(btdata1, "ATM")) { // memory on/off / general
    elm_memory = (btdata1[3] == '1' ? true : false);
    sprintf_P(btdata2, PSTR("OK\r\n>"));
  }
  else if (strstr(btdata1, "ATS")) { // space on/off / obd
    elm_space = (btdata1[3] == '1' ? true : false);
    sprintf_P(btdata2, PSTR("OK\r\n>"));
  }
  else if (strstr(btdata1, "ATH")) { // headers on/off / obd
    elm_header = (btdata1[3] == '1' ? true : false);
    sprintf_P(btdata2, PSTR("OK\r\n>"));
  }
  else if (!strcmp(btdata1, "ATSP")) { // set protocol to ? and save it / obd
    //elm_protocol = atoi(data[4]);
    sprintf_P(btdata2, PSTR("OK\r\n>"));
  }
  //else if (!strcmp(data, "ATRV")) { // read voltage in float / volts
  //  btSerial.print("12.0V\r\n>");
  //}
  // sprintf_P(cmd_str, PSTR("%02X%02X\r"), mode, pid);
  // sscanf(data, "%02X%02X", mode, pid)
  // reset dtc/ecu honda
  // 21 04 01 DA / 01 03 FC
  else if (!strcmp(btdata1, "04")) { // clear dtc / stored values
    dlcCommand(0x21, 0x04, 0x01, 0x00, dlcdata); // reset ecu
    sprintf_P(btdata2, PSTR("OK\r\n>"));
  }
  else if (!strcmp(btdata1, "0100")) {
    sprintf_P(btdata2, PSTR("41 00 BE 3E B0 11\r\n>"));
  }
  else if (!strcmp(btdata1, "0101")) { // dtc / AA BB CC DD / A7 = MIL on/off, A6-A0 = DTC_CNT
    if (dlcCommand(0x20, 0x05, 0x0B, 0x01, dlcdata)) {
      byte a = ((dlcdata[2] >> 5) & 1) << 7; // get bit 5 on dlcdata[2], set it to a7
      sprintf_P(btdata2, PSTR("41 01 %02X 00 00 00\r\n>"), a);
    }
    else {
      sprintf_P(btdata2, PSTR("DATA ERROR\r\n>"));
    }
  }
  //else if (!strcmp(btdata1, "0102")) { // freeze dtc / 00 61 ???
  //  if (dlcCommand(0x20, 0x05, 0x98, 0x02, dlcdata)) {
  //    sprintf_P(btdata2, PSTR("41 02 %02X %02X\r\n>"), dlcdata[2], dlcdata[3]);
  //  }
  //  else {
  //    sprintf_P(btdata2, PSTR("DATA ERROR\r\n>"));
  //  }
  //}
  else if (!strcmp(btdata1, "0103")) { // fuel system status / 01 00 ???
    //if (dlcCommand(0x20, 0x05, 0x0F, 0x01, dlcdata)) { // flags
    //  byte a = dlcdata[2] & 1; // get bit 0 on dlcdata[2]
    //  a = (dlcdata[2] == 1 ? 2 : 1); // convert to comply obd2
    //  sprintf_P(btdata2, PSTR("41 03 %02X 00\r\n>"), a);
    // }
    if (dlcCommand(0x20, 0x05, 0x9a, 0x02, dlcdata)) {
      sprintf_P(btdata2, PSTR("41 03 %02X %02X\r\n>"), dlcdata[2], dlcdata[3]);
    }
    else {
      sprintf_P(btdata2, PSTR("DATA ERROR\r\n>"));
    }
  }
  else if (!strcmp(btdata1, "0104")) { // engine load (%)
    if (dlcCommand(0x20, 0x05, 0x9c, 0x01, dlcdata)) {
      sprintf_P(btdata2, PSTR("41 04 %02X\r\n>"), dlcdata[2]);
    }
    else {
      sprintf_P(btdata2, PSTR("DATA ERROR\r\n>"));
    }
  }
  else if (!strcmp(btdata1, "0105")) { // ect (°C)
    if (dlcCommand(0x20, 0x05, 0x10, 0x01, dlcdata)) {
      float f = dlcdata[2];
      f = 155.04149 - f * 3.0414878 + pow(f, 2) * 0.03952185 - pow(f, 3) * 0.00029383913 + pow(f, 4) * 0.0000010792568 - pow(f, 5) * 0.0000000015618437;
      dlcdata[2] = round(f) + 40; // A-40
      sprintf_P(btdata2, PSTR("41 05 %02X\r\n>"), dlcdata[2]);
    }
    else {
      sprintf_P(btdata2, PSTR("DATA ERROR\r\n>"));
    }
  }
  else if (!strcmp(btdata1, "0106")) { // short FT (%)
    if (dlcCommand(0x20, 0x05, 0x20, 0x01, dlcdata)) {
      sprintf_P(btdata2, PSTR("41 06 %02X\r\n>"), dlcdata[2]);
    }
    else {
      sprintf_P(btdata2, PSTR("DATA ERROR\r\n>"));
    }
  }
  else if (!strcmp(btdata1, "0107")) { // long FT (%)
    if (dlcCommand(0x20, 0x05, 0x22, 0x01, dlcdata)) {
      sprintf_P(btdata2, PSTR("41 07 %02X\r\n>"), dlcdata[2]);
    }
    else {
      sprintf_P(btdata2, PSTR("DATA ERROR\r\n>"));
    }
  }
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

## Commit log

2014-04-25 Add LCD wiring image
2015-04-15 Bugfix dlc function, added hobd_uni
    [hobd_lcd.ino, hobd_uni.ino]
2015-04-15 re assigned bluetooth pin
2015-09-13 Add some custom pids, and fix some elm data conversion
    [hobd_uni.ino]
2015-09-22 Fixed hobd protocol settings on Torque
    [hobd_uni.ino]
2016-06-24 Bug fixes, Tested working.
    [hobd_uni.ino]
2016-06-29 Improvements: obd setting save to eeprom, current page save to eeprom, improve direct access to ecu address, adopt mr-sneezy's code approach
2016-10-19 Updates and enhancements, direct honda pid changed
2016-10-27 Arduino Pin remapping, code cleanups, rpm bug fix, custom cmd and API revision, redocument. etc
    [hobd_uni.ino]
2016-10-27 Update wiring image
2016-10-27 Bug fix on typos
    [hobd_uni.ino]
2017-05-17 Fixes after testing :)
    [hobd_uni.ino]
2017-07-14 MIL error display testing
    [hobd_uni.ino]
2017-07-20 Fixed Error Codes printing
    [hobd_uni.ino]
2019-03-05 Added AEM UEGO Air Fuel Ration sensor @ Analog A1 and Fuel Pressure sensor @ A2
2019-03-05 Added voltage meter again
2019-03-07 Reverting formula for afr
    [hobd_uni2.ino]
2019-10-15 Add hardware folder
    [hobd.fzz]
2019-10-15 Add code to fzz
    [hobd.fzz]
2019-11-01 rename folder, fix wiring
    [hobd.fzz]
2019-11-01 add folder
    [hobd.fzz]
2020-05-07 Local Updates
    [hobd.fzz]
2022-08-28 added torque files
    [HOBD.csv]
2022-09-19 Bugfix PID 2 mapping
    fixed relative tps PID 45 and add iacv to PID 4C
    [hobd_uni2.ino]
